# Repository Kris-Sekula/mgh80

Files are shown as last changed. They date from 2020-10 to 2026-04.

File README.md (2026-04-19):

# mgh80 - "The Arduino of the 80s"

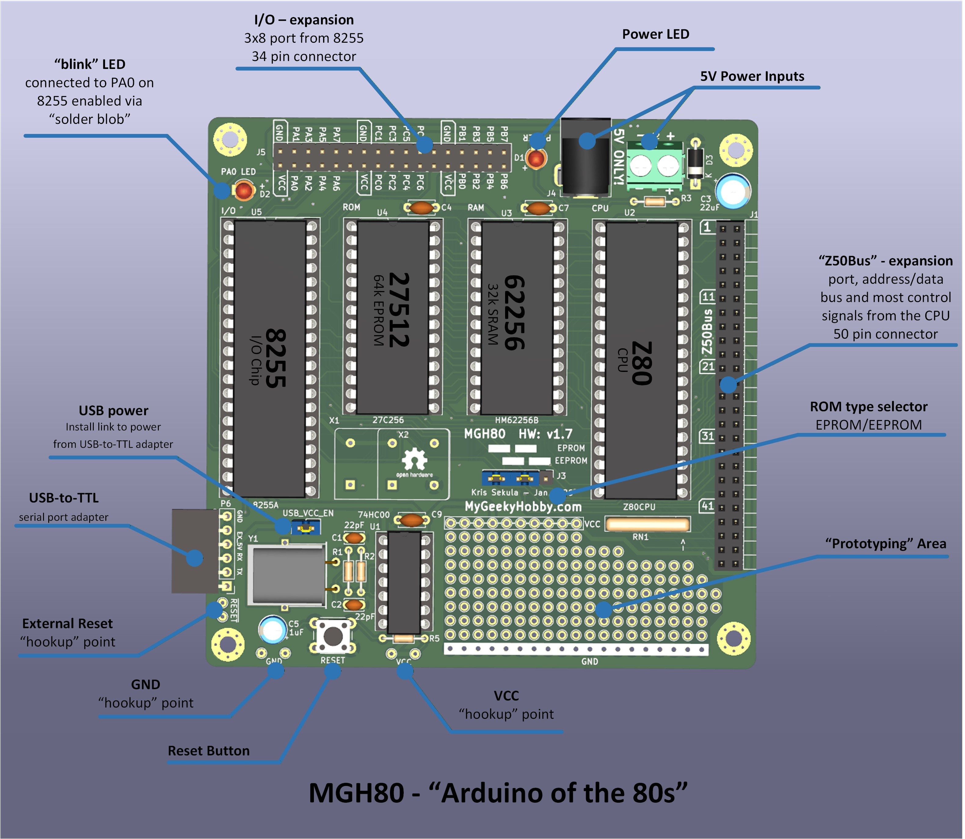
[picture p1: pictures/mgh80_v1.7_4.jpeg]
picture of v1.4c


This 5 chip Z80 single-board "computer", is a very simple Z80 based "controller" with 8255 for I/O plus a ["Z50Bus"](http://linc.no/products/z50bus/) expansion connector. I created it to kick-start my Z80 experiments - breadboarding is fun, but sometimes you want the basics to "just work" so you don't have to troubleshoot loose wires :) 

Features an option to use a local crystal-based oscillator or oscillator module. There is an onboard selector to choose between 27c256 EPROM and 28C256 EEPROM.

You can find more detailed project description on my website [mygeekyhobby.com](https://mygeekyhobby.com/2026/03/07/mgh-80-the-arduino-of-the-80s/)

Onboard address decoder:
* ROM at 0000h - 7FFFh
* RAM at 8000h - FFFFh
* IO at 00h (IOPortA)
* IO at 01h (IOPortB)
* IO at 02h (IOPortC)
* IO at 03h (Control)

A few solder jumpers allow disconnecting various onboard options (if you for example want to provide an external address decoder)... In the basic configuration you should link (with a solder blob) the following:
* JP1 - enable internal CLK source
* JP2 - enable internal IO(8255) address decoder
* JP3 - enable internal ROM address decoder
* JP4 - enable internal RAM address decoder
* JP7 - set 8255 reset pin to GND (bypass R5)
* JP8 - enable onboard LED for port A0 on the 8255
* JP9 - enable onboard IO_WR singal

Simple "blinky" program source (.asm) included and a compiled hex files (.hex) for 27C256 EPROM (or my EPROM emulator). It will toggle all lines of port A a few times a second.

In the "Monitor" folder, you will find sources for a monitor ROM — the bare-metal firmware that boots up, gives you a command prompt, and lets you inspect/modify memory, set breakpoints, and run programs.

Get your PCBs from [PCBWAY](https://www.pcbway.com/project/shareproject/mgh80___the_Arduino_of_the_80s__simple_z80_based__microcontroller____sbc_.html)

A few component kits are listed on [eBay](https://www.ebay.com/sch/avr4sale/m.html?_nkw=&_armrs=1&_ipg=&_from=)

If you found this helpful and you like the work I do, why not buy me a coffee? Thanks! :)



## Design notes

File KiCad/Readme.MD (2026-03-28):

KiCad files to produce the PCB.

Get your PCBs from

PCBWay (https://www.pcbway.com/project/shareproject/mgh80___the_Arduino_of_the_80s__simple_z80_based__microcontroller____sbc_.html)

**Please note:** The address decoder on MGH80 is very simple, as a result not all 8255 will work, (plain 8255A without any dashes in the part name seems to work best) here is a list of known working:

* KS82C55A-8CP
* CP82C55A

Version revisions:

1.7. Added P6 connector for USB-to-TTL bit banged port (see [Monitor](https://github.com/Kris-Sekula/mgh80/tree/main/Monitor#readme) folder)

1.3. Larger holes in the experiments area.

1.2. Fixed issue with EEPROM/EPROM selector.

1.1. Fixed A15 not connected issue.

1.0. First release.

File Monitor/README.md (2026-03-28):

# Simple machine code monitor for MGH80

This is a simple machine code monitor with bit-banged serial port. You can use it on mgh80 by connecting USB-TTL serial adapter as follows:

 External Signal | MGH80 J5
--- | ---
RX | PC3
TX | PC4

** The code is optimised for 4MHz clock frequency **

Example:

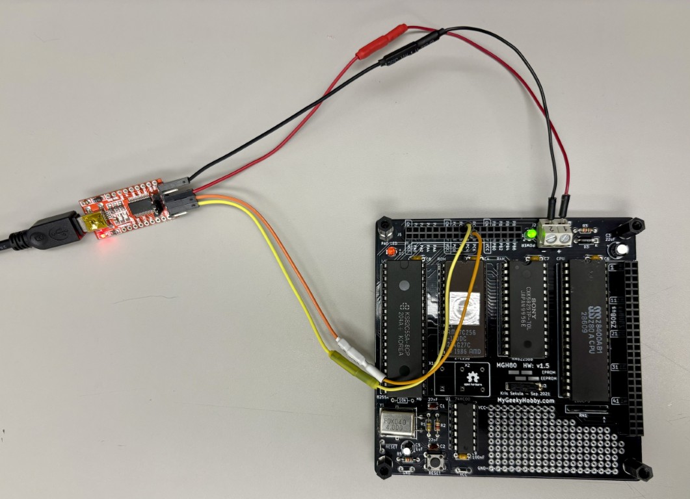
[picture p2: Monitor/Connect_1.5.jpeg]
connect pcb 1.5


If you use PCB v 1.7, I added a port for connectivity:

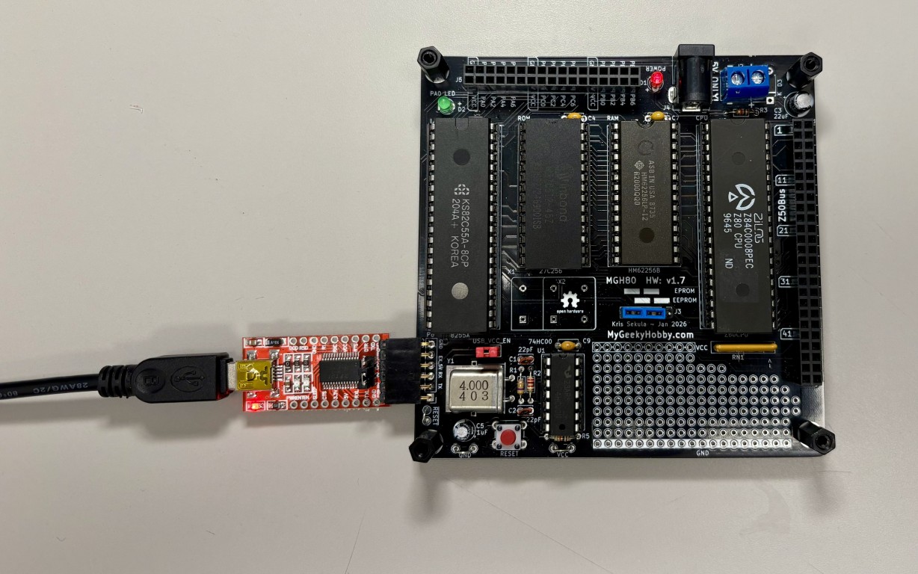
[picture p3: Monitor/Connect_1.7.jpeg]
connect pcb 1.7


I'll shorty share the PCB 1.7 desing files, but for now you can find Gerbers on [PcbWay](https://www.pcbway.com/project/shareproject/mgh80___the_Arduino_of_the_80s__simple_z80_based__microcontroller____sbc_.html)

The monitor offers various commands, hitting "m" displays the full menu:

```
  *** MGH80 - Started ***

>m
 ****** MGH80 Monitor   ***  *** [V8.3mgh 01/2026]  ******
 d  Dump Memory(16 bytes)  D  Dump Memory(256 bytes)
 S  Set Memory             T  ASCI bytes to Memory
 L  LIST                   A  ASSEMBLE
 G  Run from address       g  Run from 8100H
 B  Start BASIC            C  Clear Screen
 O  Write I/O Port         I  Read I/O Port
 f  Flash LEDs 10x         t  Beep Test
 @  Sync                   M/m  Main Menu
 :  Get iHEX Rec.(no echo)
 ;  Send iHEX Rec.(no echo)

>
```

The code includes also BASIC

This is originally based on work of Eric M. Klaus as described here: https://sites.google.com/site/ericmklaus/projects-1/z80minisystem

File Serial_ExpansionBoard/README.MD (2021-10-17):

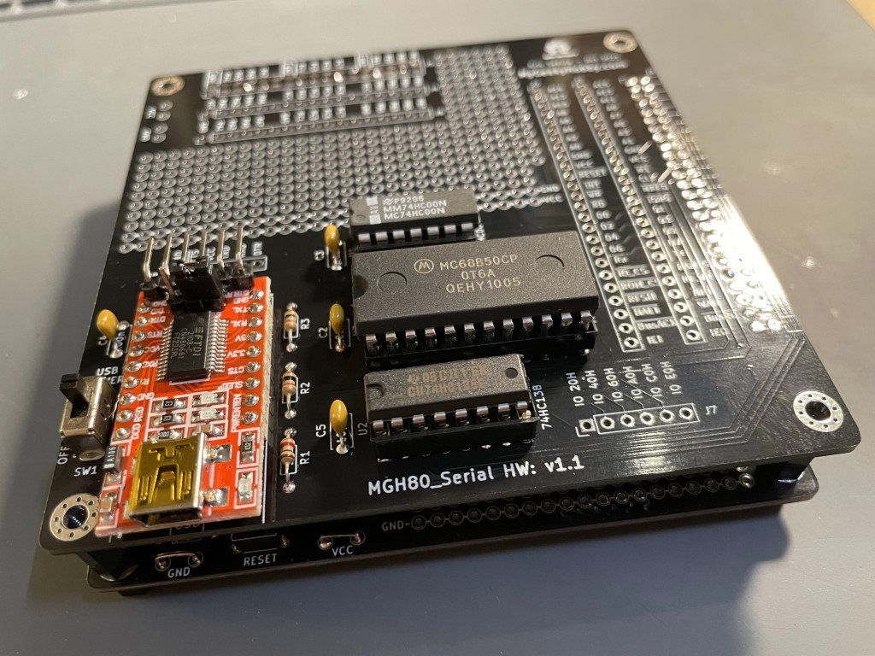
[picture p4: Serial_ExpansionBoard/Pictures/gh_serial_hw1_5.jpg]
picture of serial expansion


This is a serial expansion board using popular Motorola MC68B50. 

MGH80 + Expansion board will run BASIC or "Monitor" style program. 

I use SCMonitor-v100-R3-RC2014-32k-ROM from RC2014 project written by Stephen C Cousins in the United Kingdom.

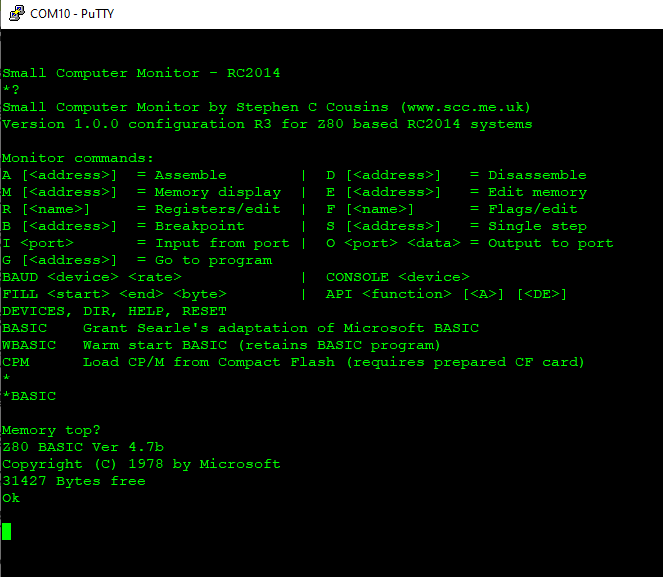
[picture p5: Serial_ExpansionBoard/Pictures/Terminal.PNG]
picture of serial expansion


You can download the monitor from his website.

Note: For this board to work correctly with MGH80 you will need to:
1. Use a 7.3728MHz crystal.
2. Disable onboard IO decoder.
3. Disable onboard IO_WR.

Note: the IO_WR signla was added to MGH80 in PCB ver 1.5, if you are using 1.4 you 
will have to cut the WR link between the Z80 and the 8255, and run IO_WR 
from the 8255 to Z50Bus pin 41. This is only needed for 82C55-2 or
82C55-5 chips, standard CP82C55A works fine.

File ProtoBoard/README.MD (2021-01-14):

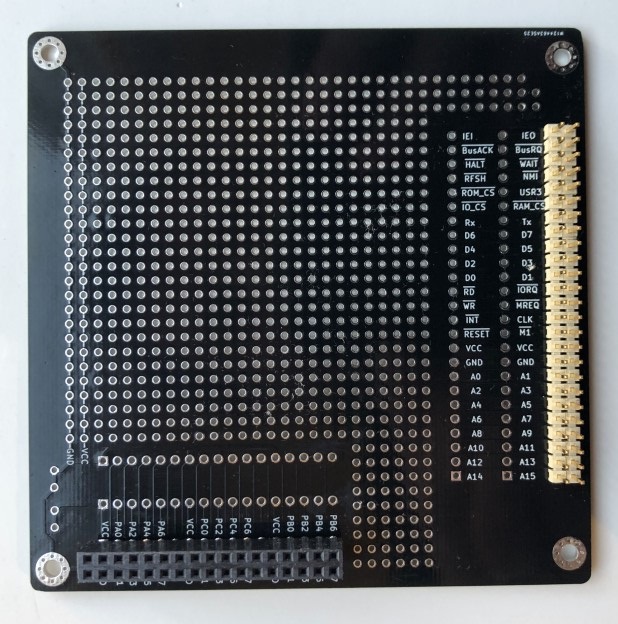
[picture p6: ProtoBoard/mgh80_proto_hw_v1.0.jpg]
picture of v1.0


This is a companion board to mgh80. It extends the I/O connections and the z80Bus to a prototyping board giving you a larger "experiments area".

All signals are marked with a label.

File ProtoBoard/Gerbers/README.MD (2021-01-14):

v1.0 produced by PCBWAY seem to work fine, there is not much to it.

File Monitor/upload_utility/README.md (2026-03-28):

# Simple upload utility

Here you will find a simple "command line" utility to upload Intel .HEX files to the MGH80 Board

This is a command line program (so simply clicking on it won't do much)

## How to use it:

### Windows executable:

From a command window prompt enter:  
```
mgh80load.exe {filename} {port#} {Y}
```

Where:

**{filename.hex}** - is the name of an intel hex file

**{port#}** - is the serial port number (number only, so put **3** instead of **COM3**) 

**{Y}** - this is optional parameter that will make the board automatically start executing code form address 0x8100h

Example:  
```
mgh80load.exe MGH80_blink.hex 3 Y
```

this will upload the file MGH80_blink.hex to the board using COM3 and start the program after upload

### Python script (linux or macOS):

Microsoft keeps making self compiled program execution more and more difficuilt. If you're having issues staring mgh80load.exe on your computer (or you want to run it on Linux machine)
Install python and run the python script, parameters are the same, here is an example:

From command prompt (or linux shell):

```
python mgh80load.py MGH80_blink.hex 3 Y
```

this will upload the file MGH80_blink.hex to the board using COM3 and start the program after upload

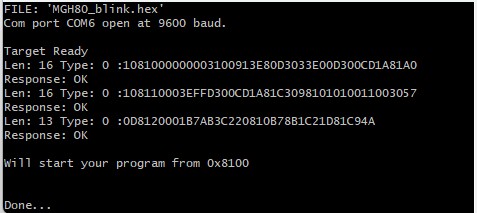
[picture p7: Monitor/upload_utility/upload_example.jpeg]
upload example


### Paste HEX file directly to the monitor:

You can also "paste" the content of the hex file into the the monitor window, but keep in mind the device has no flow controll so it is easy to overload it with text.
I succesfully used "TeraTerm" program on Windows, but added 20ms charater delay and 120ms line delay in serial settings. You only need to send data records, here is an example:

```
:1081000000003100913E80D3033E00D300CD1A81A0
:108110003EFFD300CD1A81C3098101010011003057
:0D8120001B7AB3C220810B78B1C21D81C94A
:00000001FF
```

Since we only need "data records" we can skip the last line:

```
:1081000000003100913E80D3033E00D300CD1A81A0
:108110003EFFD300CD1A81C3098101010011003057
:0D8120001B7AB3C220810B78B1C21D81C94A
```

Pasting this into TeraTerm window will "upload" into mgh80 (note there is no echo, for each line it only shows ":" for start of hex record and "*" to confirm the crc was correct for this line.

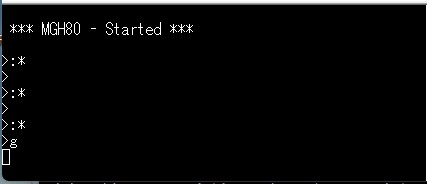
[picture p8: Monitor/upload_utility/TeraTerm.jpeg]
upload example 2


The last "g" command, starts execution.

Source for the windows utility is included.

This is originally based on work described here: https://sites.google.com/site/ericmklaus/projects-1/z80minisystem

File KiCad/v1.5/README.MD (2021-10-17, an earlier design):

In version 1.5 I introduced way to disconnect the 8255 from the Z80 WR signal by the means of jumper JP9. 
This was required as some of the 8255 were found to be problematic when using external IO Decoder (like the one used in the serial expansion board).

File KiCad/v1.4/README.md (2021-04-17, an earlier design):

In version 1.4 I've added an LED to port PA0 of the 8255, this way you can test "blinky" program without connecting external LED (similar to how it is done on a traditional Arduino board)

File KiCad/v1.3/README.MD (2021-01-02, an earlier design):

New in 1.3, increased the size of the holes in the prototyping area to allow for standard pinheaders installation.

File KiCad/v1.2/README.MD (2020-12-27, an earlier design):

Fixed issue with compatybility of the EEPROM/EPROM selector with the onboard simple address decoder. WE of the EEPROM is now plugged to a pull-up resistor via RN1.

As of December 26th 2020 Gerber files generated only but not tested yet, when I run a next batch of the PCBs I'll update here.

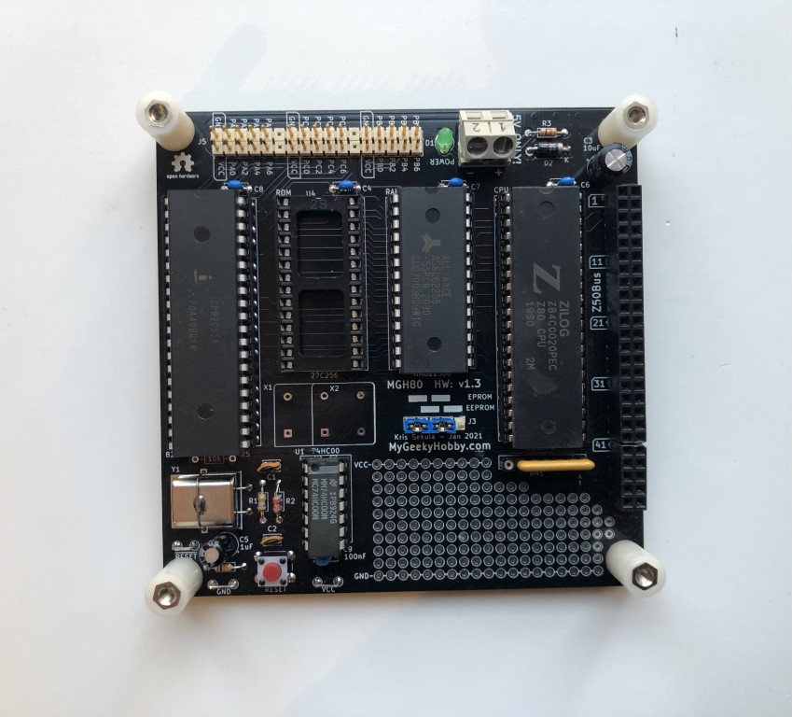
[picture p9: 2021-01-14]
mgh80_v1.3_front.jpg

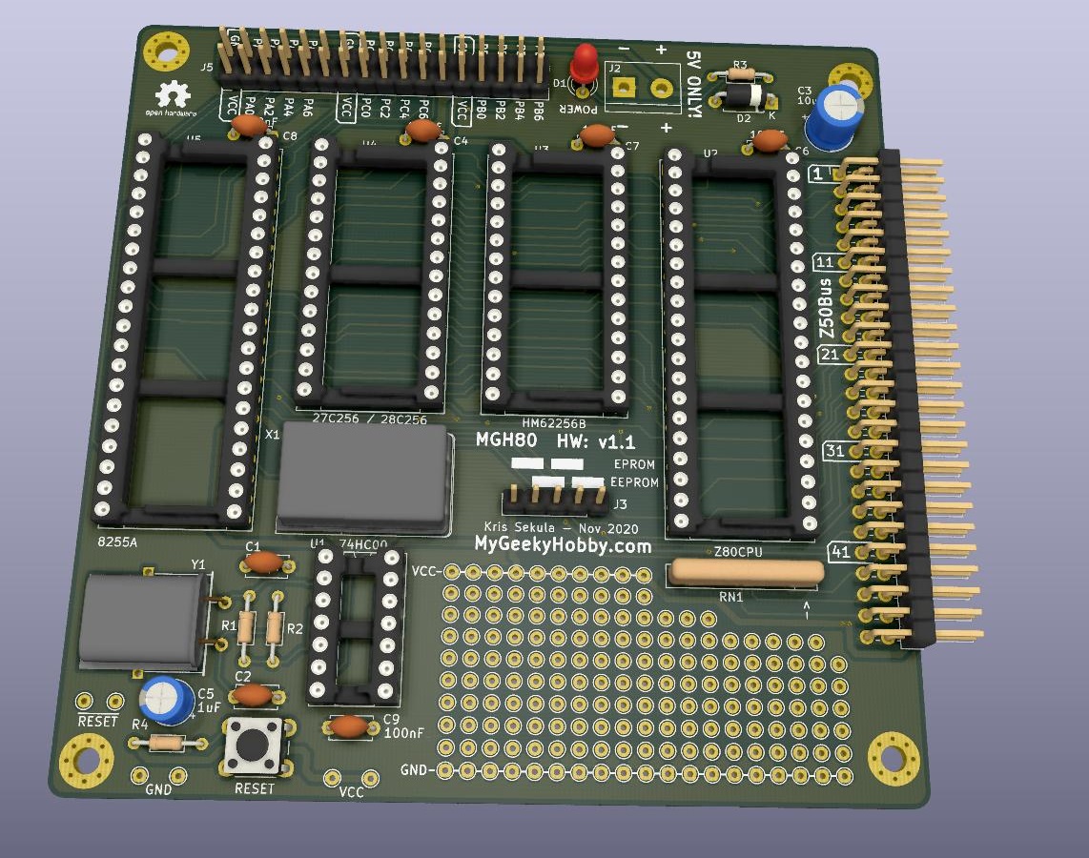
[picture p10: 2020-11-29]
mgh80_1.1.jpg

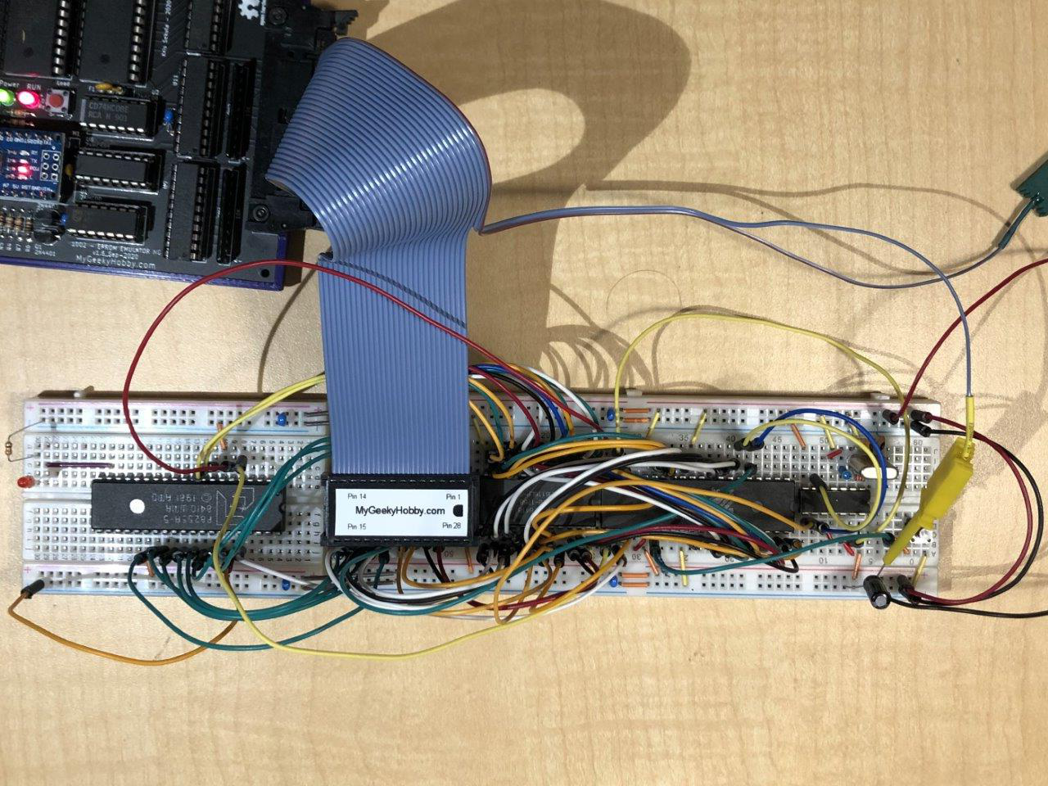
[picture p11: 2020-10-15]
Breadboard.jpg

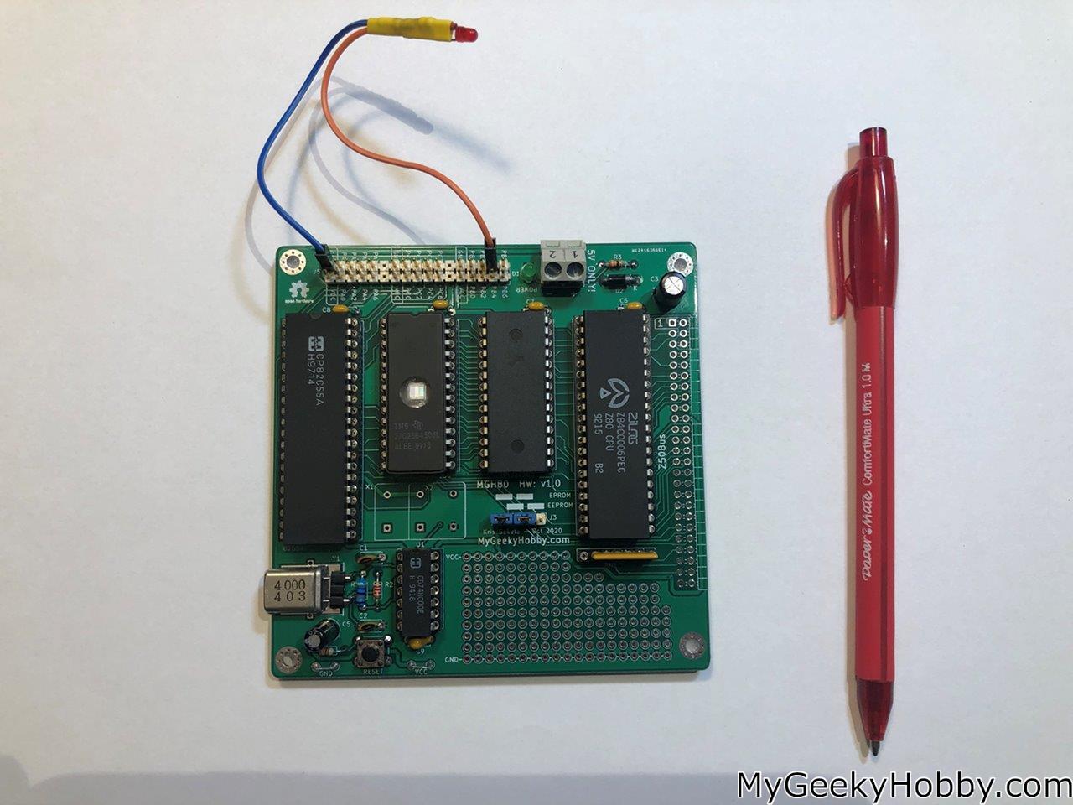
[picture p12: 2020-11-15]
MGH80_v1.0_front.jpg

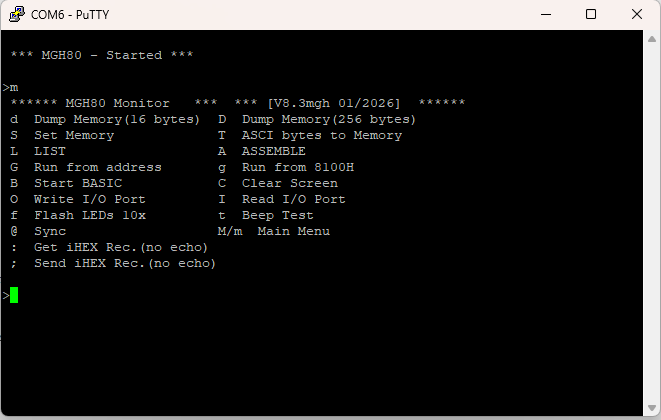
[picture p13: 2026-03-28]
Monitor/Monitor.png

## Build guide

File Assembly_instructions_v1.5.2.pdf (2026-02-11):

“MGH80” Z80 controller DIY kit – Assembly Instructions.

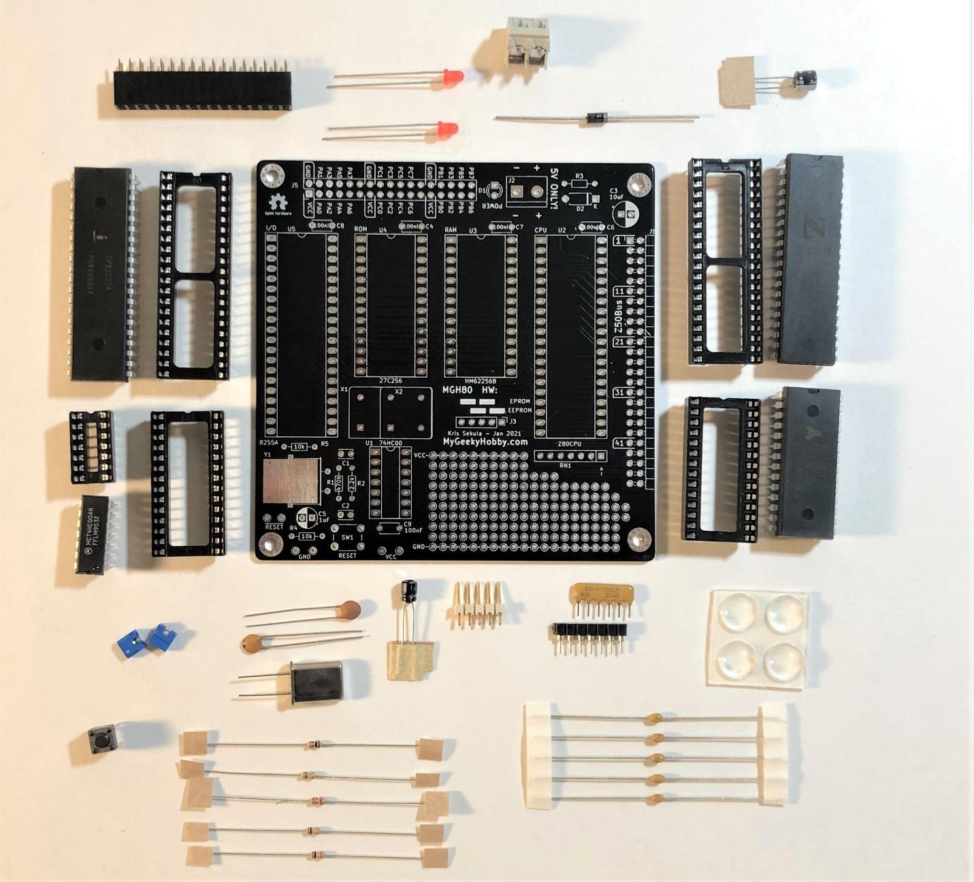
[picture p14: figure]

MyGeekyHobby.com ver 1.5.2 – February 2026

Thank you for purchasing the “MGH80” Z80 Controller DIY Kit, following is a brief assembly instruction.

MGH80 – Assembly Instructions. MyGeekyHobby.com ver 1.5.2 – Feb 2026

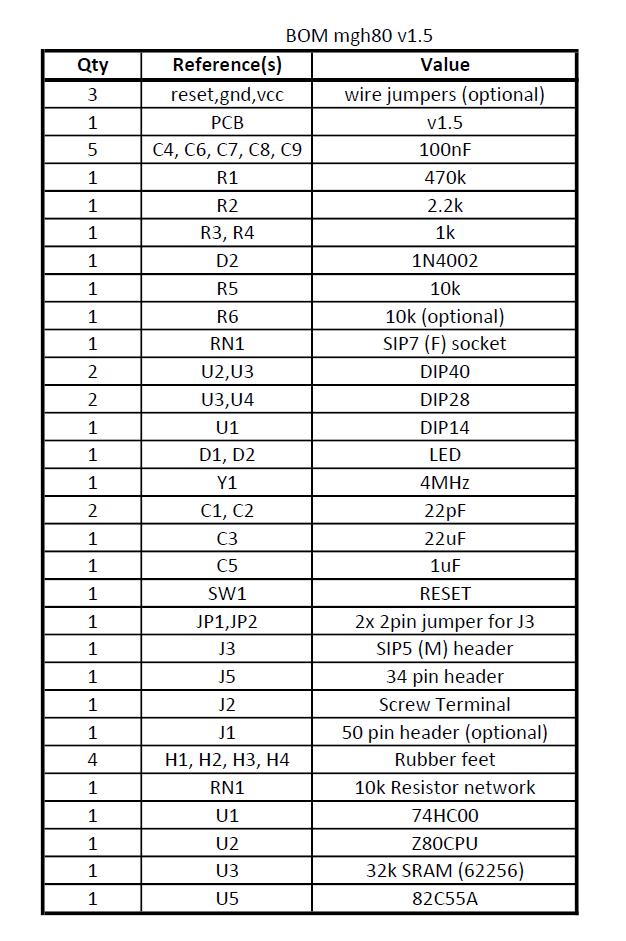
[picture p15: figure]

© MyGeekyHobby.com 2021 - 2026

This document is being updated regularly, check my GitHub page for updates:

https://github.com/Kris-Sekula/mgh80

1. Configure the board option jumpers at the bottom of the PCB.

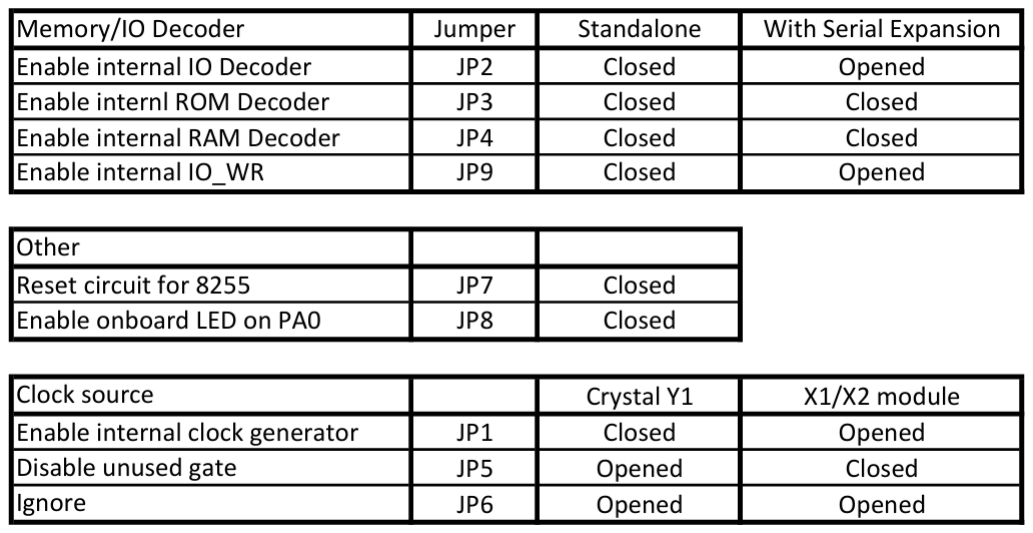
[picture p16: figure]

Basic MGH80 should be configured as follows: using a “blob” of solder close JP1, JP2, JP3, JP4 and JP7, JP8, JP9, but JP5 and JP6 are should be left opened.

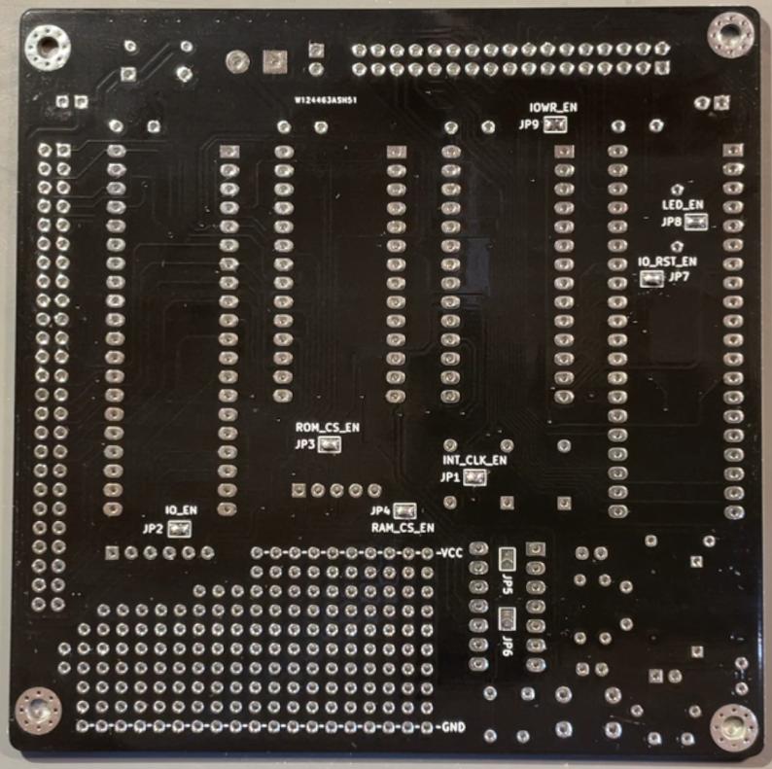
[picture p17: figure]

Note: If you are also using the “Serial Expansion board”, leave JP2 and JP9 opened.
2. Start populating components from the shortest to the tallest: R3,R4(1k), R1(470k), R2(2k2), R5(10k)…diode D3 (1N4001) pay attention to D3 polarity (white band):

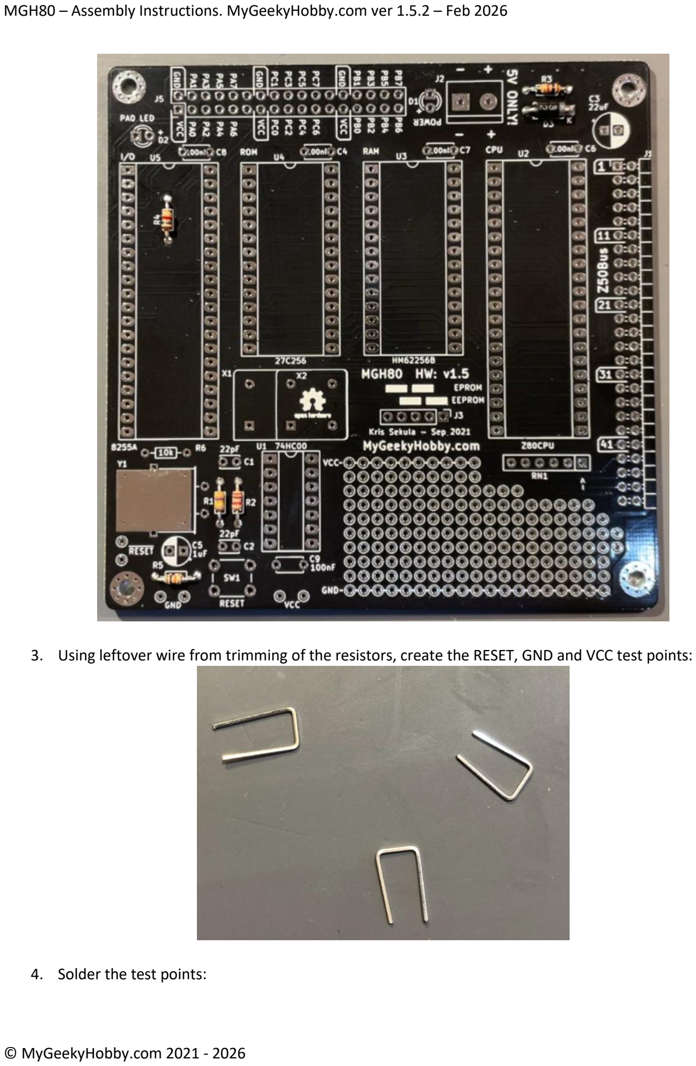
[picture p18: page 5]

3. Using leftover wire from trimming of the resistors, create the RESET, GND and VCC test points:
4. Solder the test points:

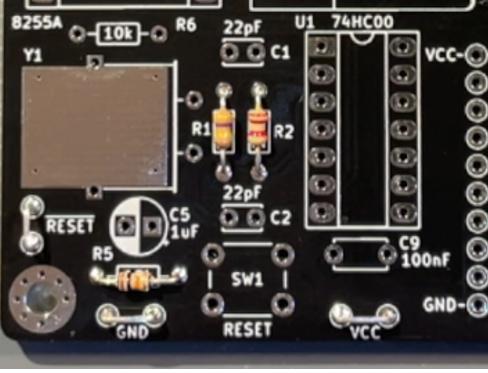
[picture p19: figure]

5. Solder the precision socket for resistor network RN1:

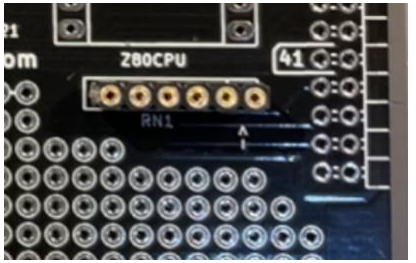
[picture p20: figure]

6. Solder IC Sockets (2x DIP28, 2x DIP40, 1x DIP14):

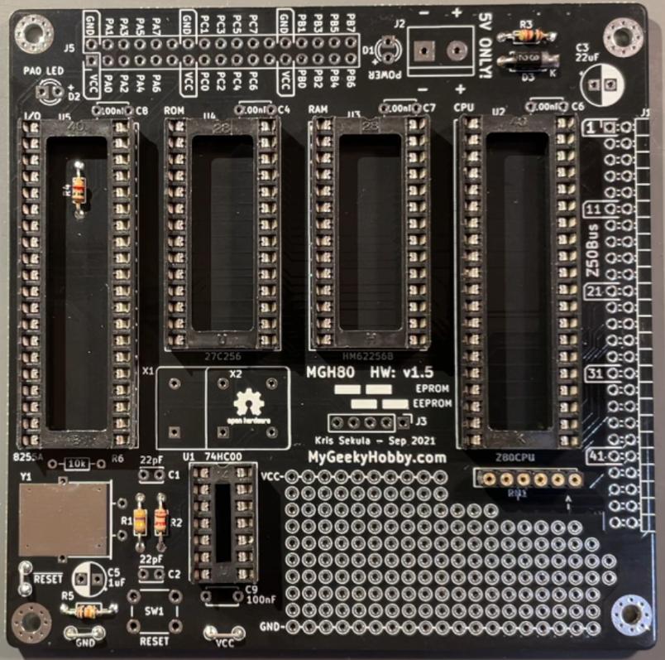
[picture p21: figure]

7. Solder 5 decoupling capacitors C4, C6, C7, C8, C9 (100nF)

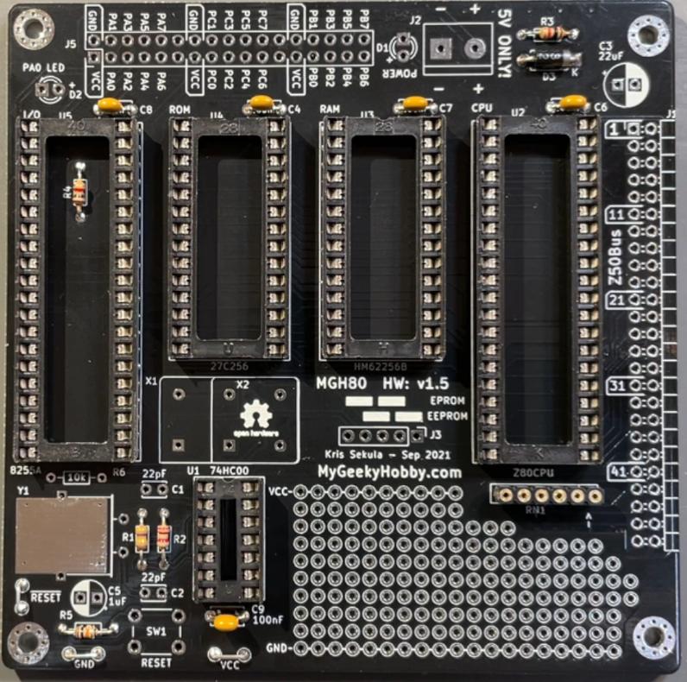
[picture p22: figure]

8. Solder the LED D1 and D2, the positive lead of the LED (Anode) is usually longer and it should be facing the “+” writing on the PCB:

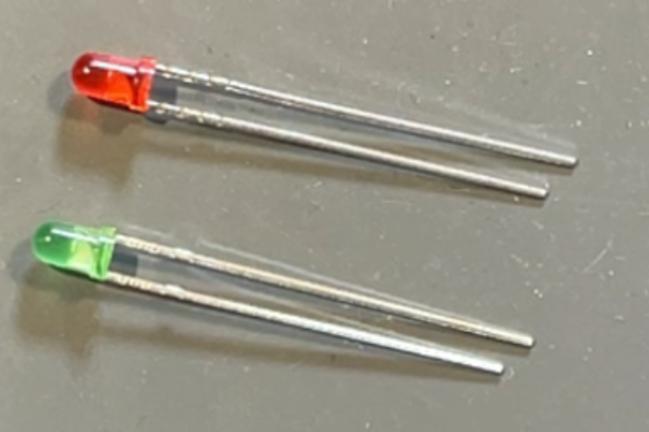
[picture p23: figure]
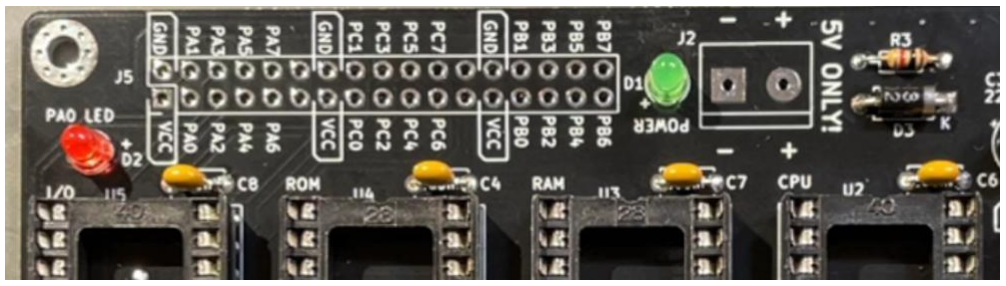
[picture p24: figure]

9. Solder the capacitor C1 and C2 – both are (22pF) and reset switch:

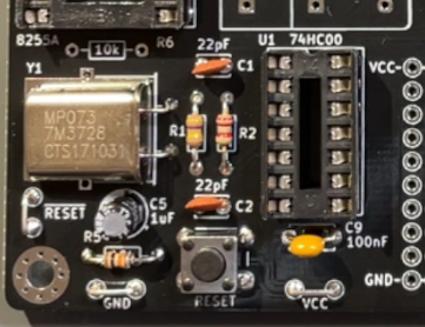
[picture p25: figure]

10. Prepare crystal oscillator Y1 by bending it’s legs 90deg, I use the edge of the PCB to help:

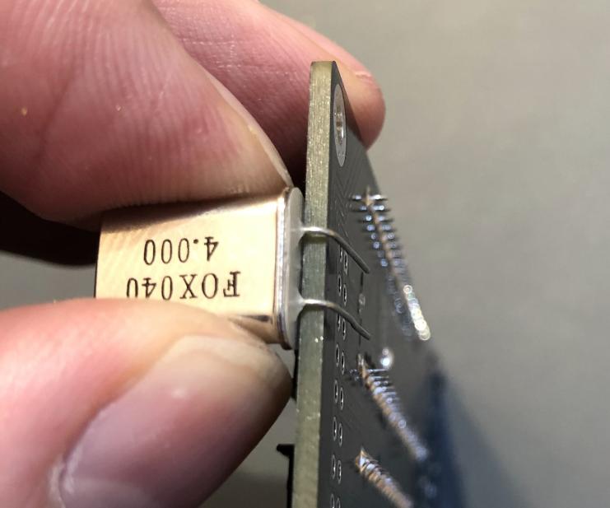
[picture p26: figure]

Note: pictured is a 4MHz crystal, but if you are using the Serial Expansion board, you will need a 7.3728MHz crystal.

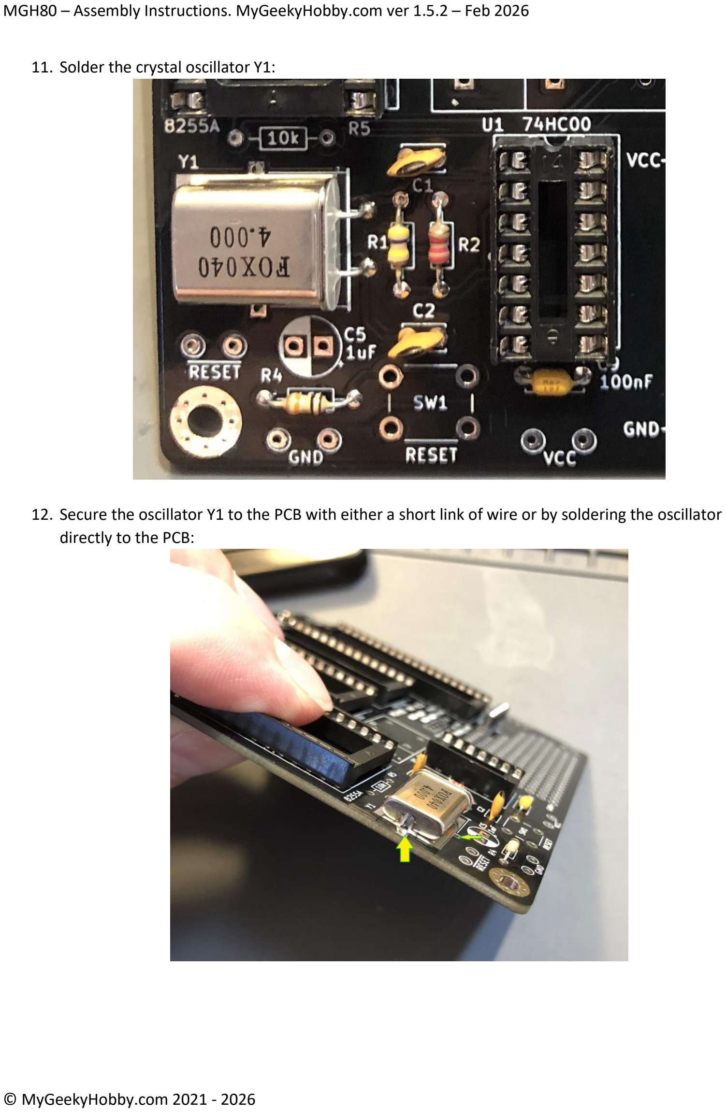
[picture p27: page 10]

11. Solder the crystal oscillator Y1:
12. Secure the oscillator Y1 to the PCB with either a short link of wire or by soldering the oscillator directly to the PCB:

13. Install the electrolytic capacitors C3 (22uF) and C5 (1uF), be careful about polarity, white band on the capacitor marks “-“.

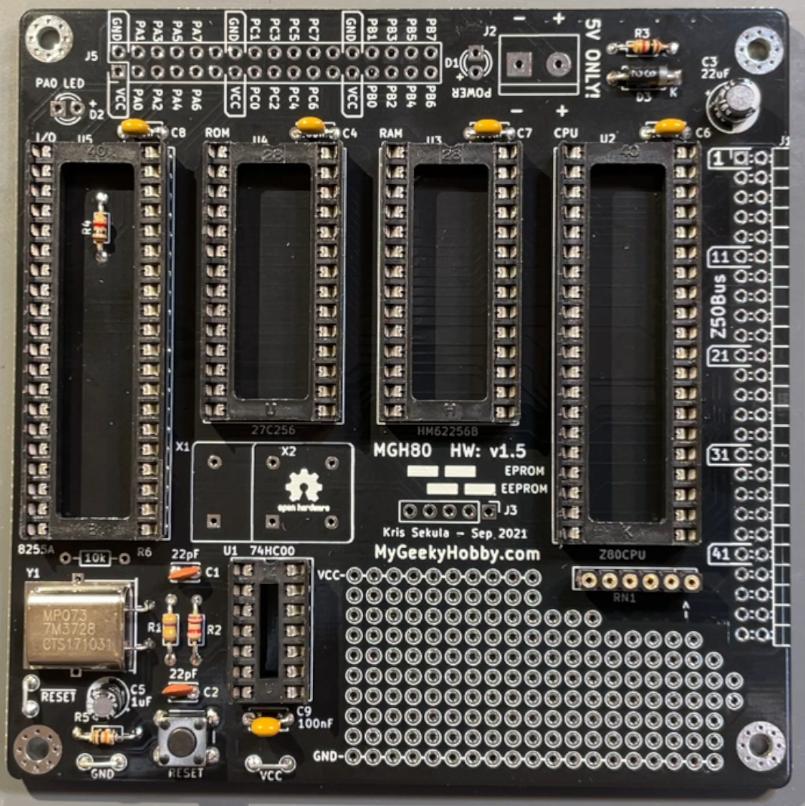
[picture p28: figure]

14. Install the 34pin female connector J5 and 5 pin male header J3

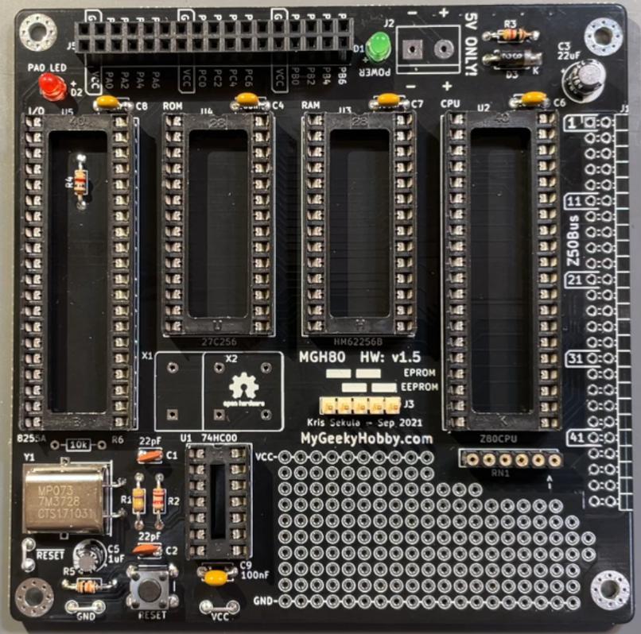
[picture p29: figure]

15. (optional) If you are planning to use the expansion board, install the z50bus connector, for “stacking” use 50 pin female header, for “bus” expander, use a 90deg bent 50pin male header:

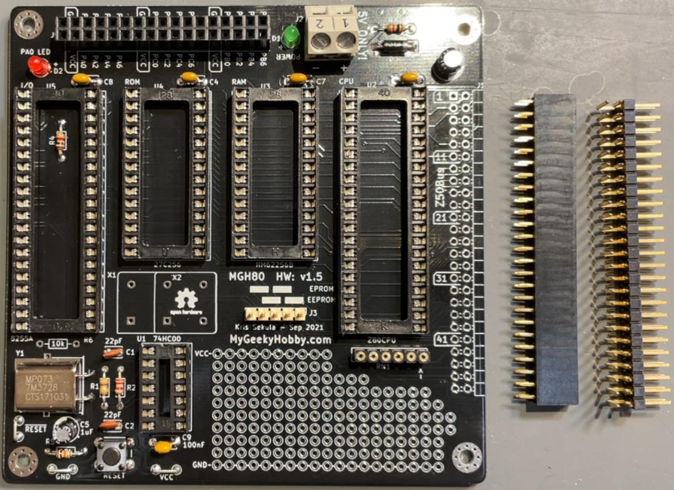
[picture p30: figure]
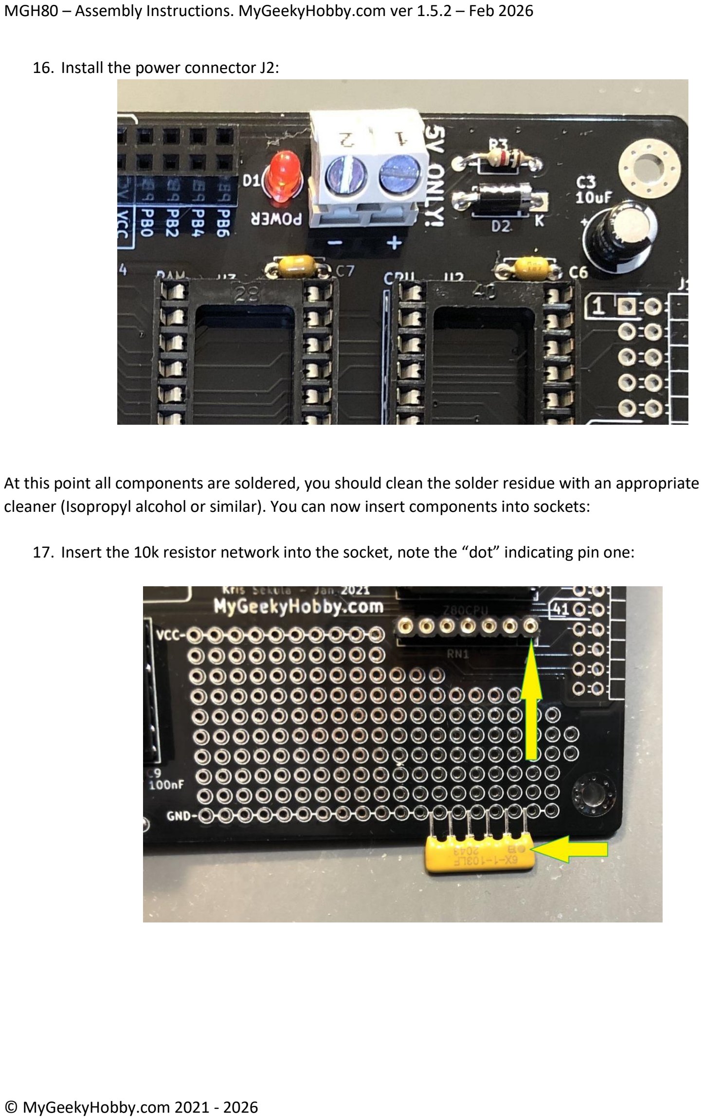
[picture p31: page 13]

16. Install the power connector J2:

At this point all components are soldered, you should clean the solder residue with an appropriate cleaner (Isopropyl alcohol or similar). You can now insert components into sockets:

17. Insert the 10k resistor network into the socket, note the “dot” indicating pin one:

18. Insert the CPU in U2, the RAM in U3 and the IO in U5 and the logic gate into U1

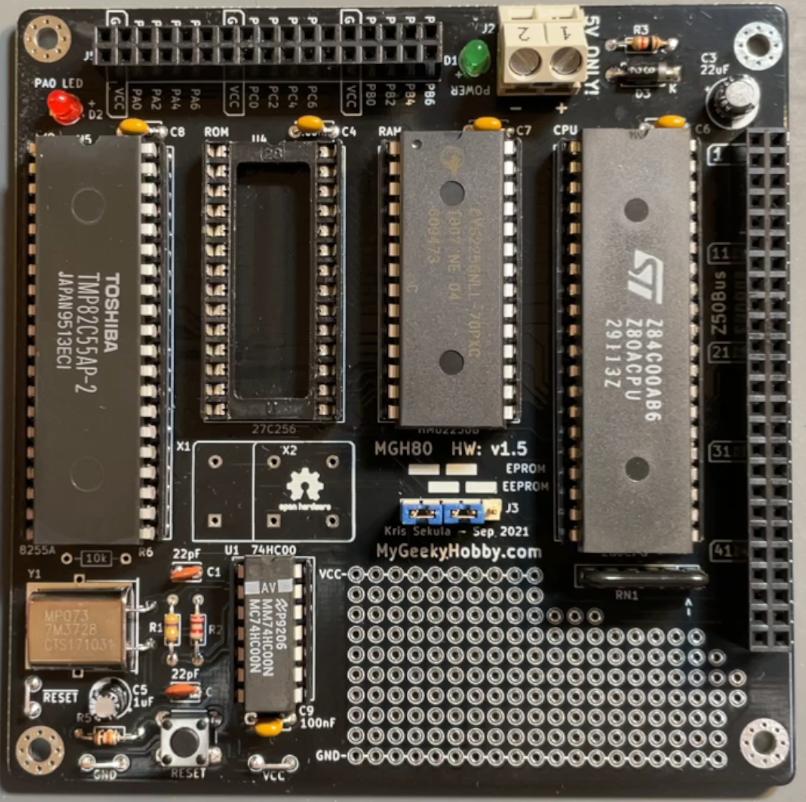
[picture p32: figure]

19. Attach the provided rubber feet to the bottom of the PCB.

20. Depending on the type of ROM used, configure J3 jumpers:
a. 27C256 EPROM memory (blue jumpers on the left of J3) like this:

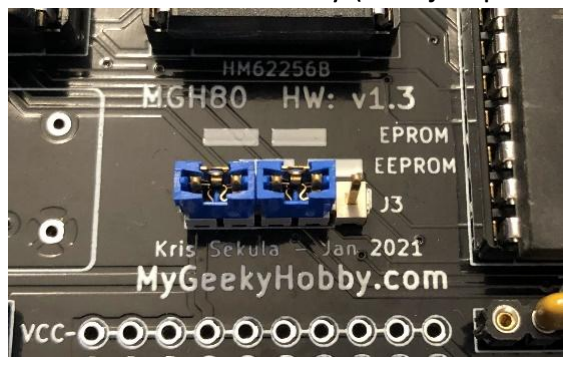
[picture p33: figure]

b. AT28C256 EEPROM (jumpers should be placed to the right of J3).

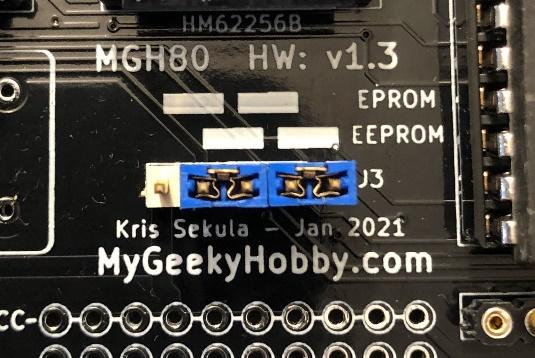
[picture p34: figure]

c. W27C512 EEPROM from Winbond: those as pretty cheap on eBay and are pin compatible with EPROM but can be erased electricaly (I’m using the cheap TL866 programmer). Jumpers should be configured as per example a. (EPROM) and since this memory is 64k, you should load the program into the programmer starting at address 0x8000h (as A15 is held high for the 27C256).

You “MGH80” system is ready to use, you can find a simple “blink” program in the GitHub repository.

Legal Notice:

THE SOFTWARE, DESIGN AND/OR HARDWARE IS PROVIDED “AS IS”, WITHOUT WARRANTY OF ANY KIND, EXPRESS OR IMPLIED, INCLUDING BUT NOT LIMITED TO THE WARRANTIES OF MERCHANTABILITY, FITNESS FOR A PARTICULAR PURPOSE AND NONINFRINGEMENT. IN NO EVENT SHALL THE AUTHORS OR COPYRIGHT HOLDERS BE LIABLE FOR ANY CLAIM, DAMAGES OR OTHER LIABILITY, WHETHER IN AN ACTION OF CONTRACT, TORT OR OTHERWISE, ARISING FROM, OUT OF OR IN CONNECTION WITH THE SOFTWARE OR THE USE OR OTHER DEALINGS IN THE SOFTWARE.

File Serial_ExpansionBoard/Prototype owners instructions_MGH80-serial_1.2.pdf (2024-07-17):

MGH80 pcb v1.4b or lower, compatibility with serial expansion card modifications

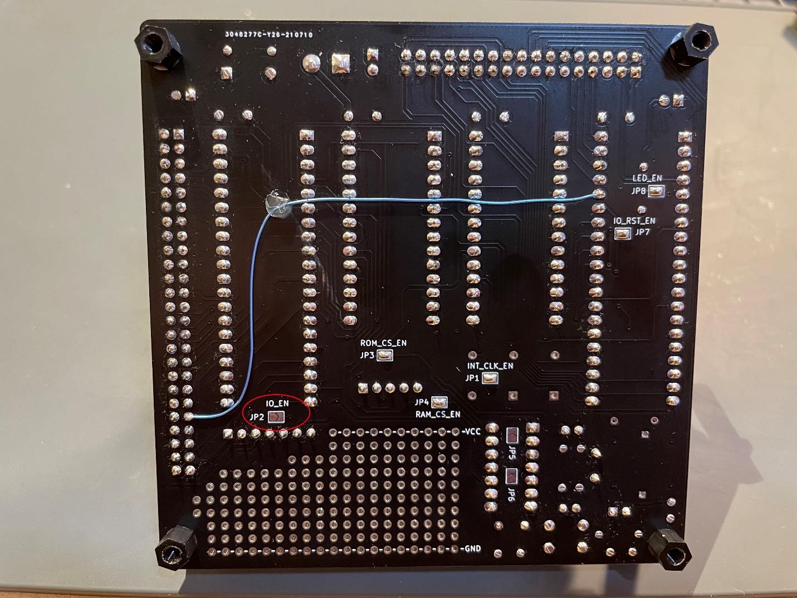
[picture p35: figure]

Document version 1.2

Here are all the information you need to use your MGH80-Serial expansion board (prototype).

I will publish all the information as soon as I have the new PCB version ready and tested, for now attached is just the schematic diagram version 1.1 (your PCB is 1.0 but has been modified to function as 1.1).

To successfully use this expansion board you will need to:

1. Add the provided 50pin female header to your MGH80 (J1).
2. Replace the 4MHz quartz with the provided 7.3728MHz one.
3. Remove the IO_EN solder blob on MGH80 to disable the simple onboard “IO decoder” (see the red circle in the picture below).
4. If your MGH80 is using any PPI chip other than the CP82C55 (for example the TOSHIBA TMP8255AP-2, you will have to modify the MGH PCB to “inject” the new “/IO_WR” signal by cutting the track going to pin 36 of the 8255(WR) and routing pin 41 (USER3) from J1 to pin 36 on the 8255 as pictured.

Re-route pin 41 (USER3) from J1 to pin 36 on 8255

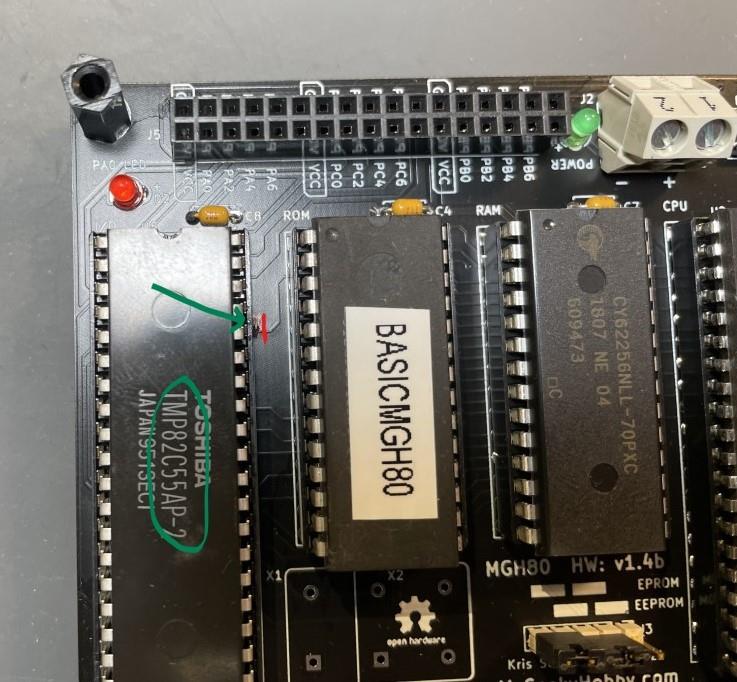
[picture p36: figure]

Cut the /WR signal going to the 8255

5. In terms of firmware you can use the provided EPROM and load “SCMonitor-v100-R3-RC2014-32k-ROM.hex”, for your convenience I already programmed the EPROM, but note you are not paying for the firmware as it is free of charge. This firmware has not been written by me, but is open source and available on the internet. I’ve reached out to the author to get an official permission to distribute the code with my board.
6. A few words on power: the serial expansion board comes with a USB-TTL adapter that can provide power to both the serial adapter and MGH80. There is also a power switch on-board, you should turn it into the ON position, if you want the USB port to be the source of power. Otherwise you can keep it in the OFF position. Note, even in the OFF position the small red LED on the serial adapter will be lit up.

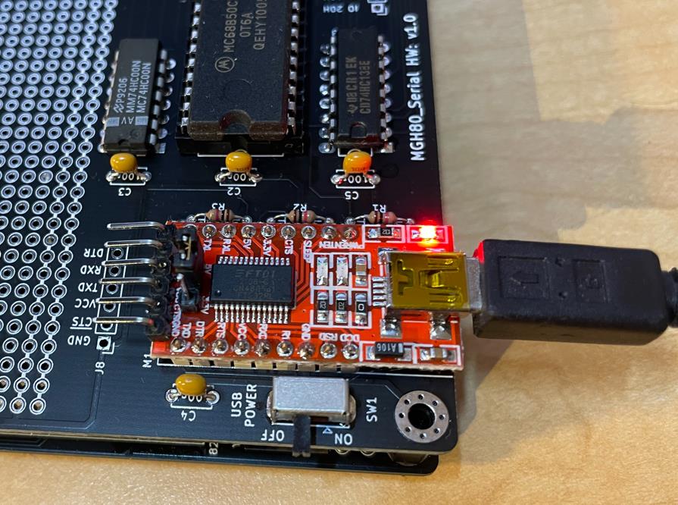
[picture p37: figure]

7. Establishing connection: you will need a serial terminal (screen or putty), set the speed to 115200. The board will initially boot to the SCM “monitor”, you can do some low level commands there (for example to set all lines of port A of the 8255 to logic “1” you would send the following commands:

“o 3 80” command translates to set I/O port 03h to 80h (that is the address of control byte that sets all ports of the 8255 as outputs, “o 0 ff” changes the lines of Port A to “1” and “o 0 0” changes the level back to “0” on all outputs of port A.

8. Here is how you start BASIC, from the “monitor” start by typing “BASIC”, when it asks “Memory top?” just hit enter. The small example basic program shows how to control the ports of the 8255 (note basic is not using hex by default, so parameters are provided in decimal).

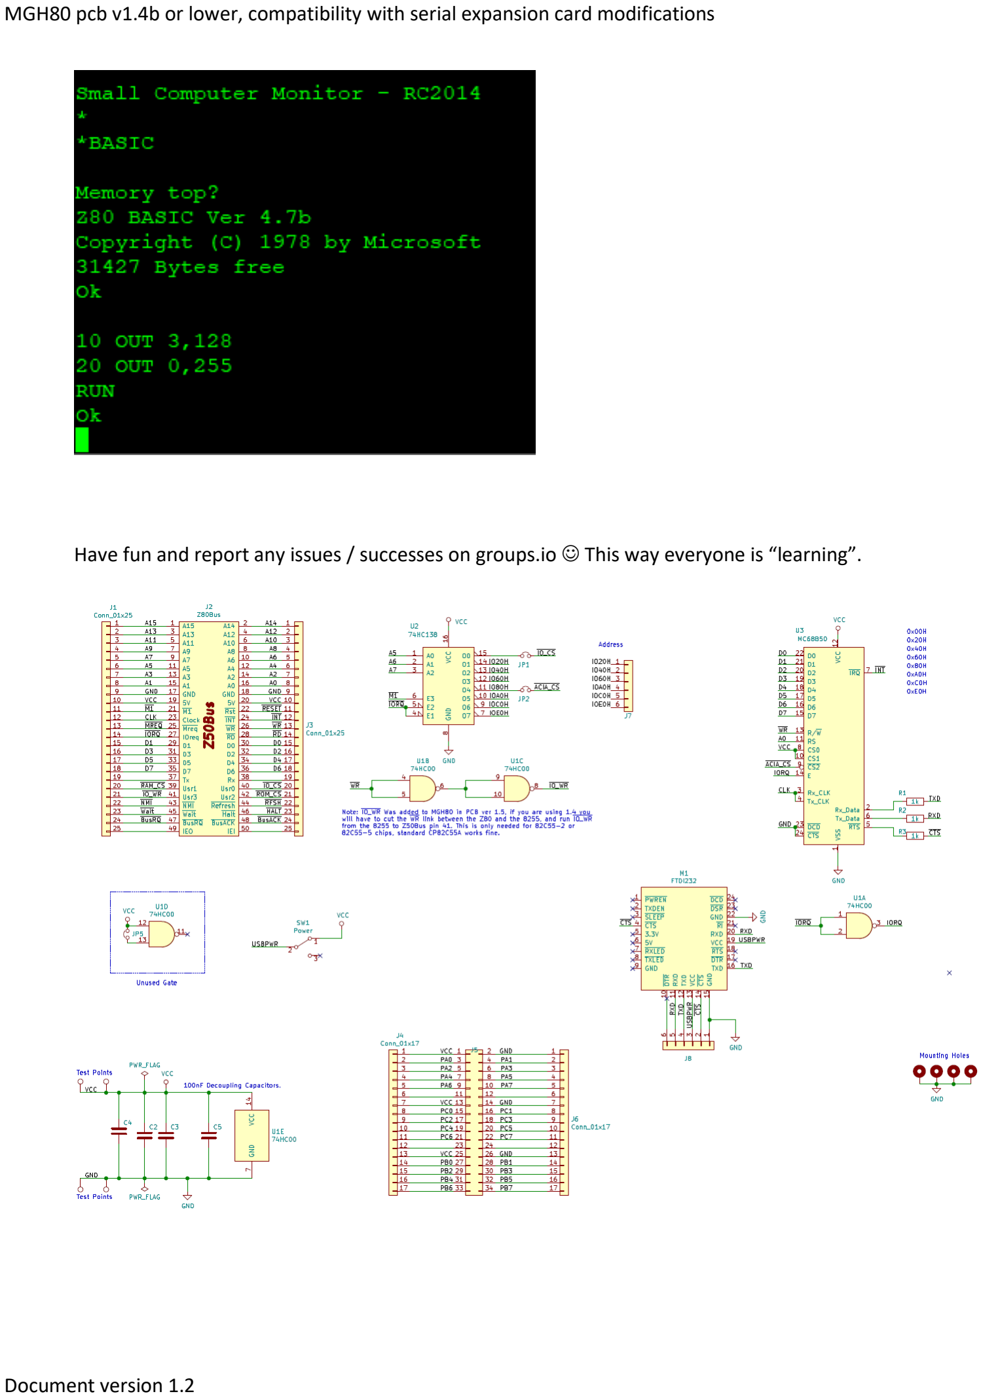
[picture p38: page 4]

Have fun and report any issues / successes on groups.io This way everyone is “learning”.

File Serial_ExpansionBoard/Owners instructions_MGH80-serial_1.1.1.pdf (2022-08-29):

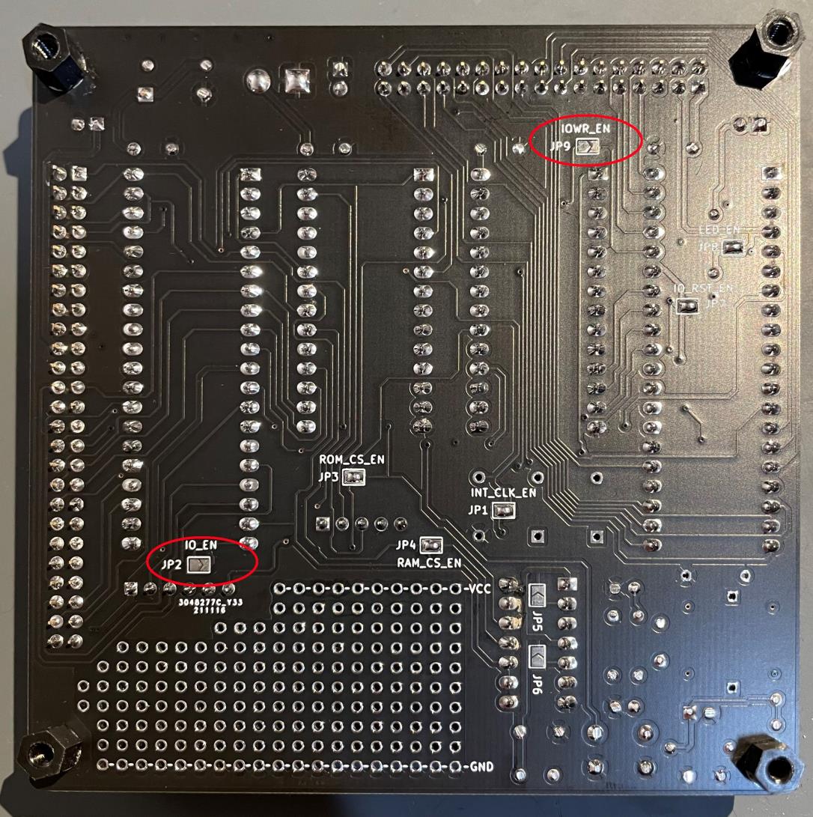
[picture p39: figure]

Doc version 1.1.1

Here are all the information you need to use your MGH80-Serial expansion board.

To successfully use this expansion board you will need to:

1. Double check that you are using 7.3728MHz or 3.6864MHz crystal.
2. Re-configure the solder bridges on MGH80 as follows:
a. Make sure JP9 (IOWR_EN) is left open.
b. Make sure JP2 (IO_EN) is left open.

3. Configure the Serial Expansion board as follows:
a. JP1 (IO_CS) - closed
b. JP2 (ACIA_CS) – closed.
c. JP5 – Closed

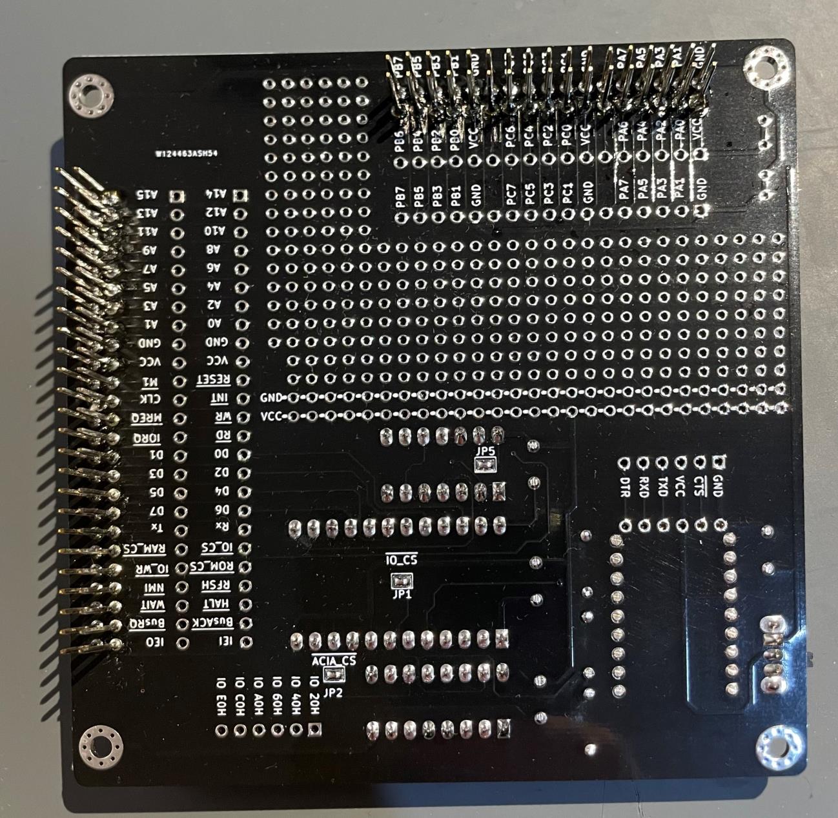
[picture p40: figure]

4. In terms of firmware you can use the provided EPROM and load “SCMonitor-v100-R3-RC2014-32k-ROM.hex”, for your convenience I already programmed the EPROM, but note you are not paying for the firmware as it is free of charge. This firmware has not been written by me, but is open source and available on the internet. I’ve reached out to the author to get an official permission to distribute the code with my board.
5. A few words on power: the serial expansion board comes with a USB-TTL adapter that can provide power to both the serial adapter and MGH80. There is also a power switch on-board, you should turn it into the ON position, if you want the USB port to be the source of power. Otherwise you should keep it in the OFF position. Note, even in the OFF position the small red LED on the serial adapter will still be lit up.


6. Establishing connection: you will need a serial terminal (screen or putty), set the speed to 115200kbps (or 57600bps if 3.6864 MHz crystal is used) . The board will initially boot to the SCM “monitor”, you can do some low level commands there (for example to set all lines of port A of the 8255 to logic “1” you would send the following commands:

“o 3 80” command translates to set I/O port 03h to 80h (that is the address of control byte that sets all ports of the 8255 as outputs, “o 0 ff” changes the lines of Port A to “1” and “o 0 0” changes the level back to “0” on all outputs of port A.

7. Here is how you start BASIC, from the “monitor” start by typing “BASIC”, when it asks “Memory top?” just hit enter. The small example basic program shows how to control the ports of the 8255 (note basic is not using hex by default, so parameters are provided in decimal).

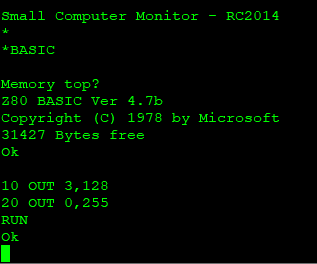
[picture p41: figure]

Have fun and report any issues / successes on groups.io This way everyone is “learning”.

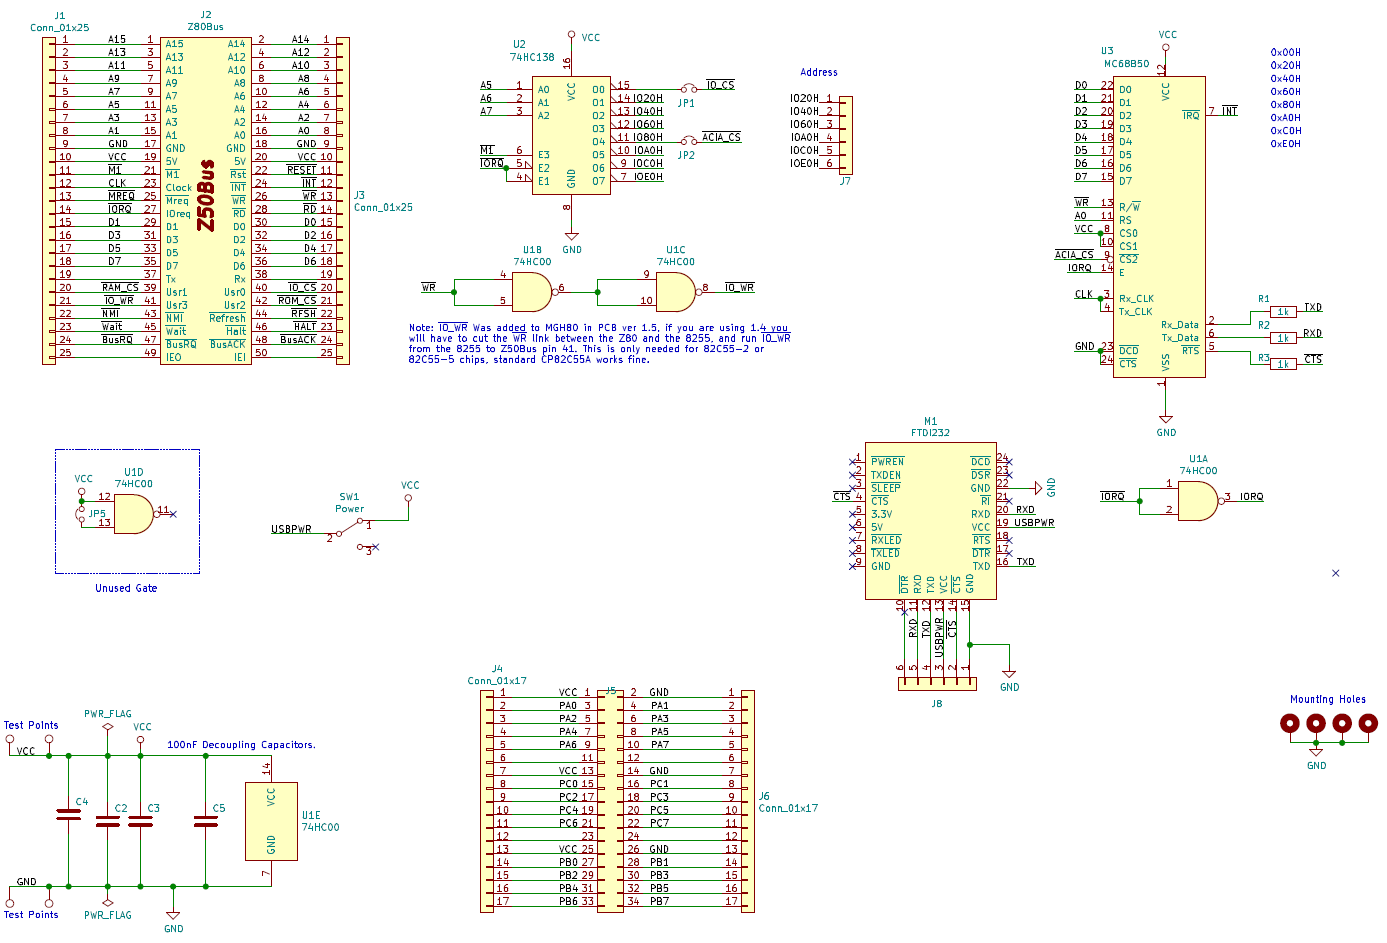
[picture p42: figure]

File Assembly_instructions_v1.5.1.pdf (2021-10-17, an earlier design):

“MGH80” Z80 controller DIY kit – Assembly Instructions.

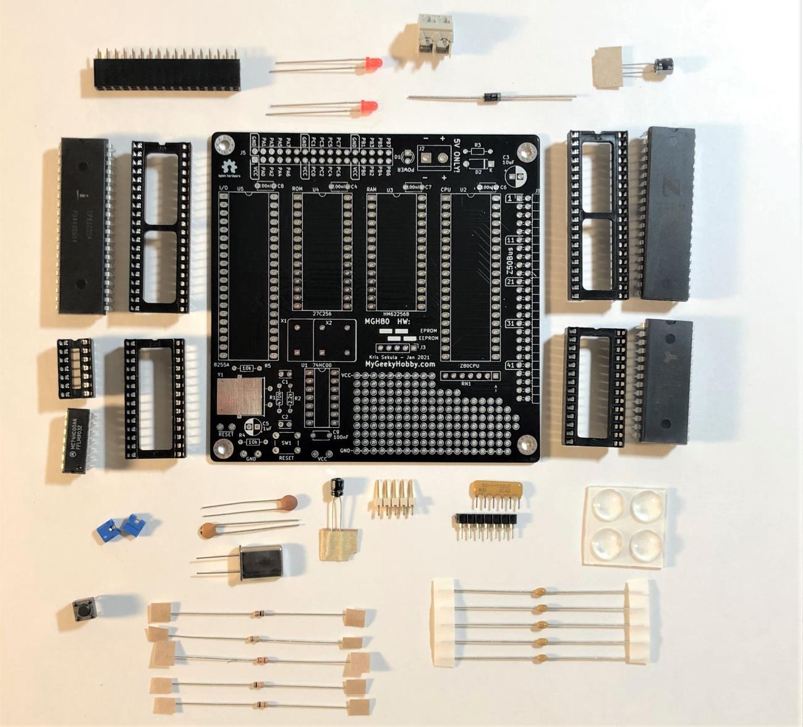
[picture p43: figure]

MyGeekyHobby.com ver 1.5.1 – October 2021

Thank you for purchasing the “MGH80” Z80 Controller DIY Kit, following is a brief assembly instruction.

MGH80 – Assembly Instructions. MyGeekyHobby.com ver 1.5.1 – Oct 2021


© MyGeekyHobby.com 2021

This document is being updated regularly, check my GitHub page for updates:

https://github.com/Kris-Sekula/mgh80

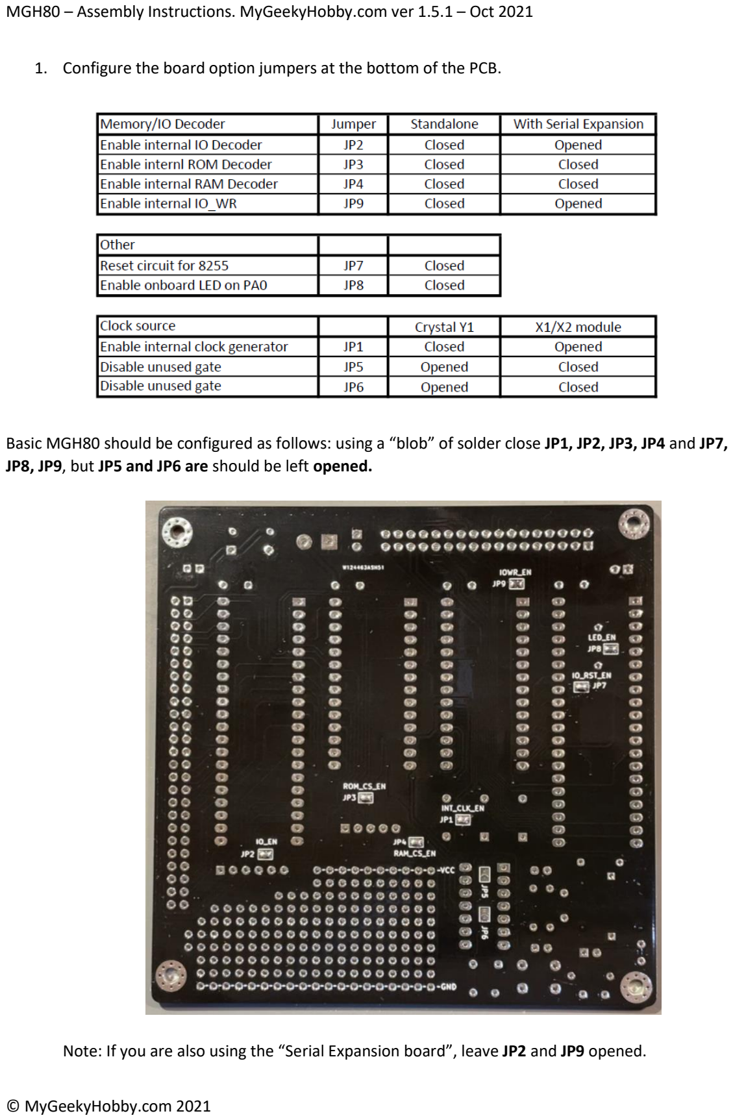
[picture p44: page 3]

1. Configure the board option jumpers at the bottom of the PCB.

Basic MGH80 should be configured as follows: using a “blob” of solder close JP1, JP2, JP3, JP4 and JP7, JP8, JP9, but JP5 and JP6 are should be left opened.

Note: If you are also using the “Serial Expansion board”, leave JP2 and JP9 opened.

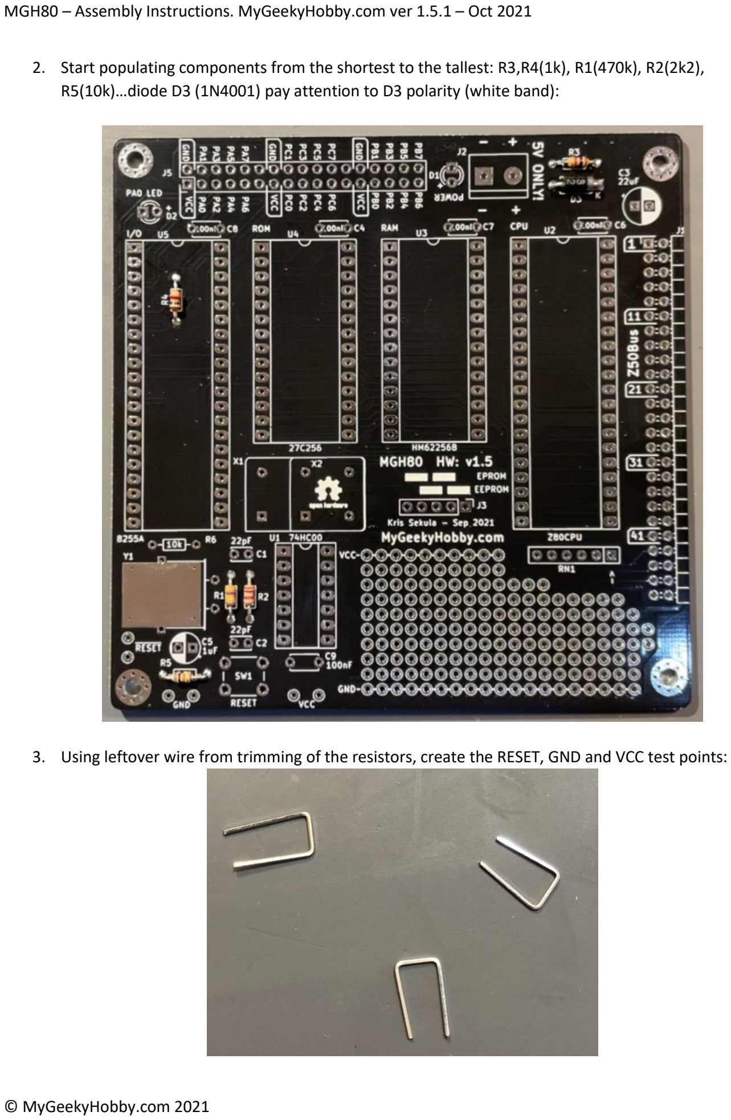
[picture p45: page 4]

2. Start populating components from the shortest to the tallest: R3,R4(1k), R1(470k), R2(2k2), R5(10k)…diode D3 (1N4001) pay attention to D3 polarity (white band):
3. Using leftover wire from trimming of the resistors, create the RESET, GND and VCC test points:

4. Solder the test points:

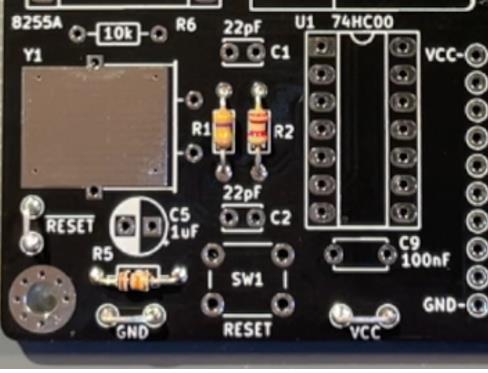
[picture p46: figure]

5. Solder the precision socket for resistor network RN1:

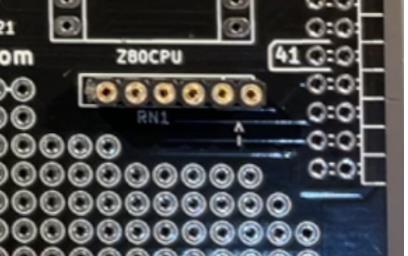
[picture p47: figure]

6. Solder IC Sockets (2x DIP28, 2x DIP40, 1x DIP14):

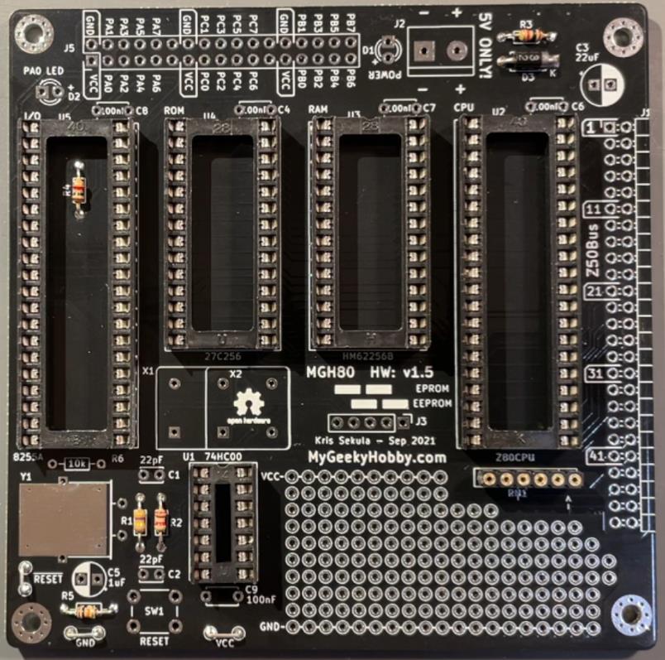
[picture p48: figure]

7. Solder 5 decoupling capacitors C4, C6, C7, C8, C9 (100nF)

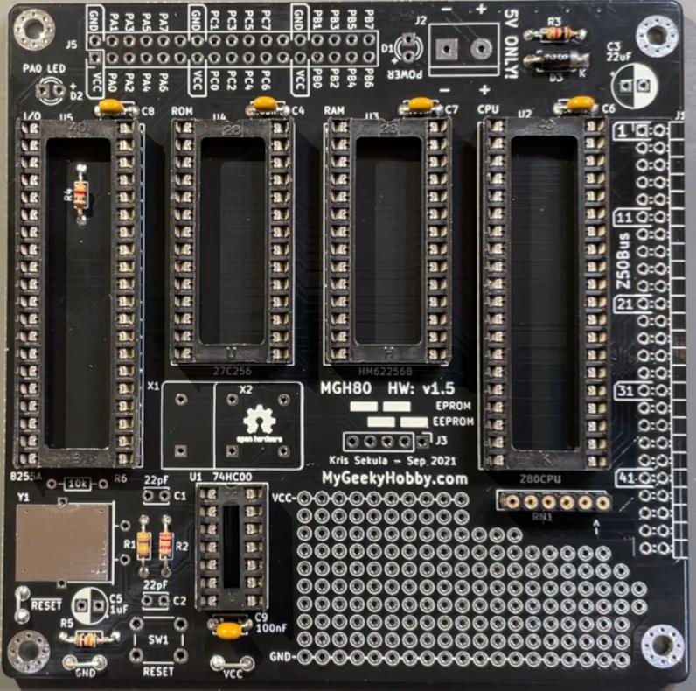
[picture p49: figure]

8. Solder the LED D1 and D2, the positive lead of the LED (Anode) is usually longer and it should be facing the “+” writing on the PCB:

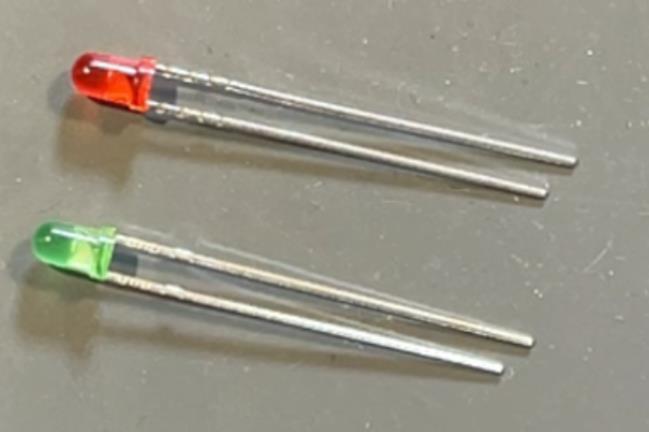
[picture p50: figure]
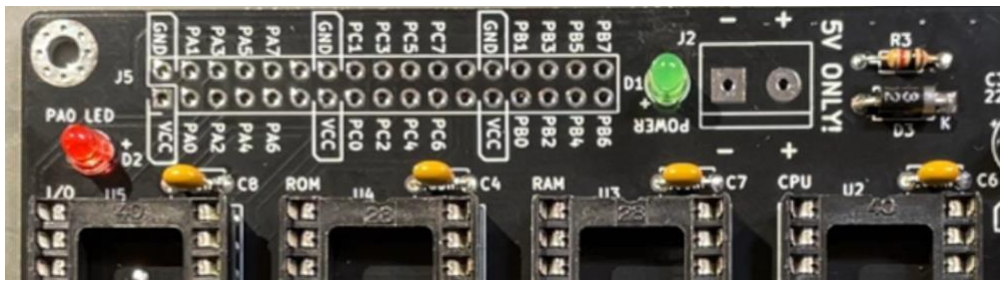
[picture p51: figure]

9. Solder the capacitor C1 and C2 – both are (22pF) and reset switch:

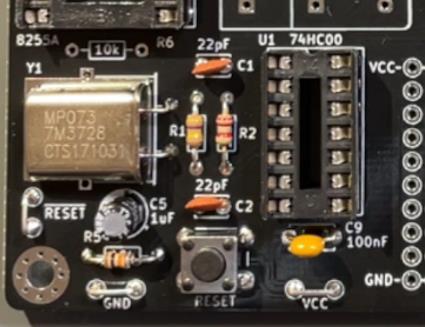
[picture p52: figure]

10. Prepare crystal oscillator Y1 by bending it’s legs 90deg, I use the edge of the PCB to help:

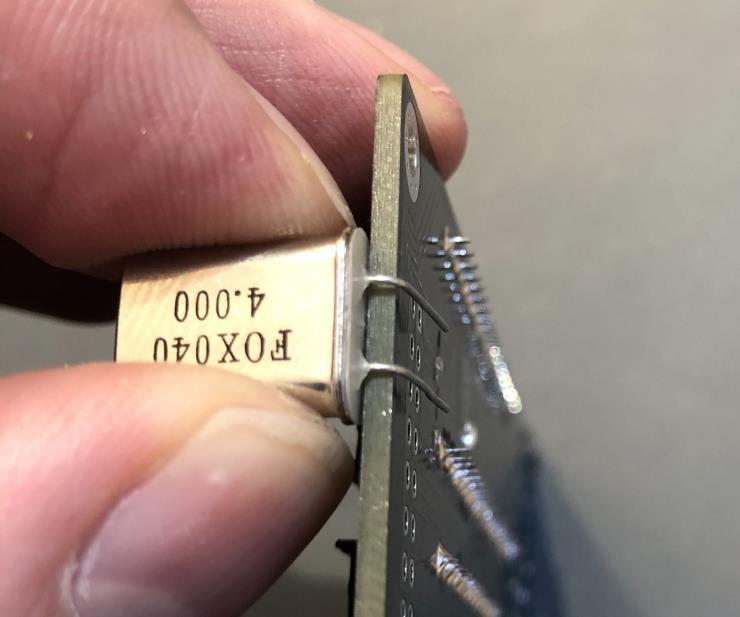
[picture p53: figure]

Note: pictured is a 4MHz crystal, but if you are using the Serial Expansion board, you will need a 7.3728MHz crystal.


11. Solder the crystal oscillator Y1:
12. Secure the oscillator Y1 to the PCB with either a short link of wire or by soldering the oscillator directly to the PCB:

13. Install the electrolytic capacitors C3 (22uF) and C5 (1uF), be careful about polarity, white band on the capacitor marks “-“.


14. Install the 34pin female connector J5 and 5 pin male header J3


15. (optional) If you are planning to use the expansion board, install the z50bus connector, for “stacking” use 50 pin female header, for “bus” expander, use a 90deg bent 50pin male header:


16. Install the power connector J2:

At this point all components are soldered, you should clean the solder residue with an appropriate cleaner (Isopropyl alcohol or similar). You can now insert components into sockets:

17. Insert the 10k resistor network into the socket, note the “dot” indicating pin one:

18. Insert the CPU in U2, the RAM in U3 and the IO in U5 and the logic gate into U1


19. Attach the provided rubber feet to the bottom of the PCB.

20. Depending on the type of ROM used, configure J3 jumpers:
a. 27C256 EPROM memory (blue jumpers on the left of J3) like this:


b. AT28C256 EEPROM (jumpers should be placed to the right of J3).


c. W27C512 EEPROM from Winbond: those as pretty cheap on eBay and are pin compatible with EPROM but can be erased electricaly (I’m using the cheap TL866 programmer). Jumpers should be configured as per example a. (EPROM) and since this memory is 64k, you should load the program into the programmer starting at address 0x8000h (as A15 is held high for the 27C256).

You “MGH80” system is ready to use, you can find a simple “blink” program in the GitHub repository.

Legal Notice:

THE SOFTWARE, DESIGN AND/OR HARDWARE IS PROVIDED “AS IS”, WITHOUT WARRANTY OF ANY KIND, EXPRESS OR IMPLIED, INCLUDING BUT NOT LIMITED TO THE WARRANTIES OF MERCHANTABILITY, FITNESS FOR A PARTICULAR PURPOSE AND NONINFRINGEMENT. IN NO EVENT SHALL THE AUTHORS OR COPYRIGHT HOLDERS BE LIABLE FOR ANY CLAIM, DAMAGES OR OTHER LIABILITY, WHETHER IN AN ACTION OF CONTRACT, TORT OR OTHERWISE, ARISING FROM, OUT OF OR IN CONNECTION WITH THE SOFTWARE OR THE USE OR OTHER DEALINGS IN THE SOFTWARE.

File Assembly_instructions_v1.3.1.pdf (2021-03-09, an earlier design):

“MGH80” Z80 controller DIY kit – Assembly Instructions.


MyGeekyHobby.com ver 1.3.1 – March 2021

MGH80 – Assembly Instructions. MyGeekyHobby.com ver 1.3.1 – March 2021


© MyGeekyHobby.com 2021

Thank you for purchasing the “MGH80” Z80 Controller DIY Kit, following is a brief assembly instruction.

This document is being updated regularly, check my GitHub page for updates:

https://github.com/Kris-Sekula/mgh80

1. Configure the board option jumpers at the bottom of the PCB. Using a solder “blob” connect JP1, JP2, JP3, JP4 and JP7 as highlighted in yellow. JP5 and JP6 are should be left opened.


2. Start populating components from the shortest to the tallest: R3(1k), R1(470k), R2(2k2), R4(10k)… additionally if the supplied 100nF capacitors are the axial type, insert those into the PCB (C8, C4, C7, C6, C9) solder and trim:
3. Using leftover wire from trimming of the resistors, create the RESET, GND and VCC test points:

4. Solder the test points:


(note: other components are shown already soldered, but I changed the order of operations)


5. Solder the precision socket for resistor network RN1:


6. Solder IC Sockets (2x DIP28, 2x DIP40, 1x DIP14):
7. Solder the LED, the positive lead of the LED (Anode) should be facing the “POWER” writing on the PCB:


8. Solder the capacitor C1 and C2 – both are (22pF):
9. Prepare crystal oscillator Y1 by bending it’s legs 90deg, I use the edge of the PCB to help:


10. Solder the crystal oscillator Y1:
11. Secure the oscillator Y1 to the PCB with either a short link of wire or by soldering the oscillator directly to the PCB:


12. Install the electrolytic capacitors:

C5 is 1uF but C3 can be either 10uF or 22uF

13. Install the 34pin female connector J5 and 5 pin male header J3


14. Install the power connector J2:

At this point all components are soldered, you should clean the solder residue with an appropriate cleaner (Isopropyl alcohol or similar). You can now insert components into sockets:

15. Insert the 10k resistor network into the socket, note the “dot” indicating pin one:

16. Insert the CPU in U2, the RAM in U3 and the IO in U5 and the logic gate into U1


17. Attach the provided rubber feet to the bottom of the PCB.

18. Depending on the type of ROM used, configure J3 jumpers:
a. 27C256 EPROM memory (blue jumpers on the left of J3) like this:


b. AT28C256 EEPROM (jumpers should be placed to the right of J3).


c. W27C512 EEPROM from Winbond: those as pretty cheap on eBay and are pin compatible with EPROM but can be erased electricaly (I’m using the cheap TL866 programmer). Jumpers should be configured as per example a. (EPROM) and since this memory is 64k, you should load the program into the programmer starting at address 0x8000h (as A15 is held high for the 27C256).

You “MGH80” system is ready to use, you can find a simple “blink” program in the GitHub repository.

Legal Notice:

THE SOFTWARE, DESIGN AND/OR HARDWARE IS PROVIDED “AS IS”, WITHOUT WARRANTY OF ANY KIND, EXPRESS OR IMPLIED, INCLUDING BUT NOT LIMITED TO THE WARRANTIES OF MERCHANTABILITY, FITNESS FOR A PARTICULAR PURPOSE AND NONINFRINGEMENT. IN NO EVENT SHALL THE AUTHORS OR COPYRIGHT HOLDERS BE LIABLE FOR ANY CLAIM, DAMAGES OR OTHER LIABILITY, WHETHER IN AN ACTION OF CONTRACT, TORT OR OTHERWISE, ARISING FROM, OUT OF OR IN CONNECTION WITH THE SOFTWARE OR THE USE OR OTHER DEALINGS IN THE SOFTWARE.

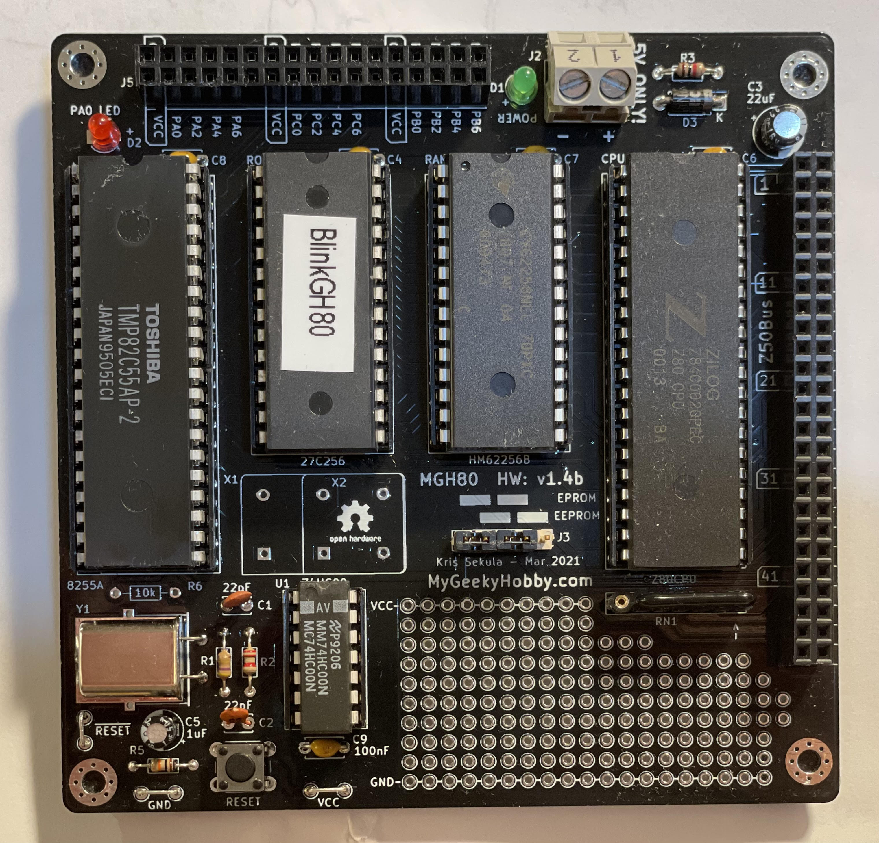
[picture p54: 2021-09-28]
pictures/1.4b_assembled.jpg

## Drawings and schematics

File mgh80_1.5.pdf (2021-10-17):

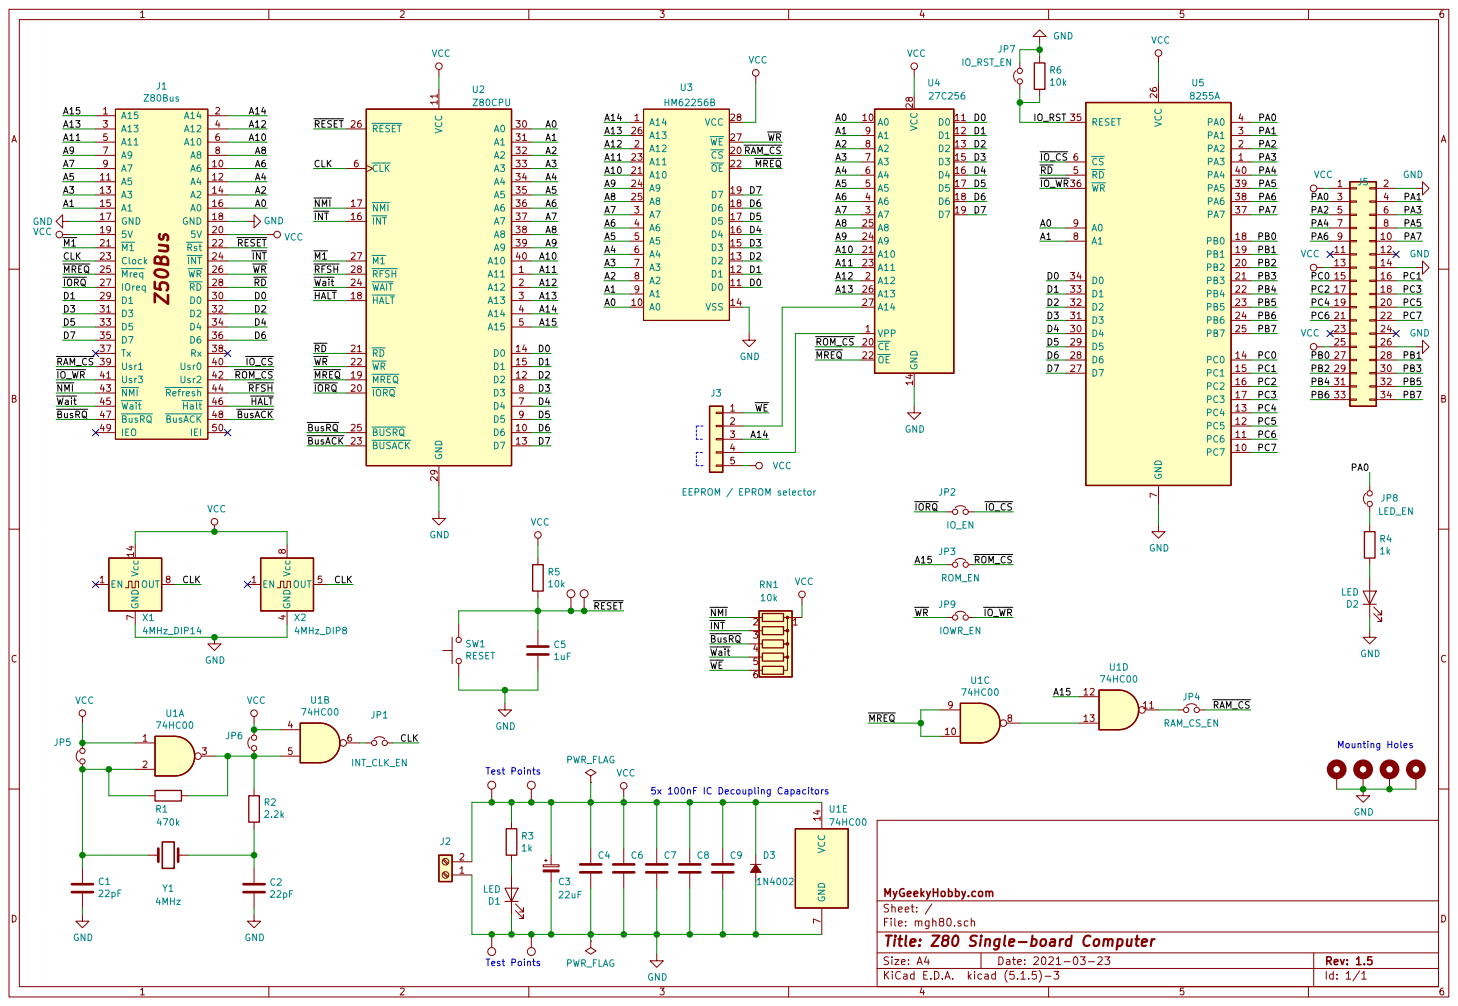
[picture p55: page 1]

J3 EEPROM / EPROM selector VCC

Mounting Holes Test Points

File: mgh80.sch Sheet: / MyGeekyHobby.com Y1

Id: 1/1 Title: Z80 Single-board Computer

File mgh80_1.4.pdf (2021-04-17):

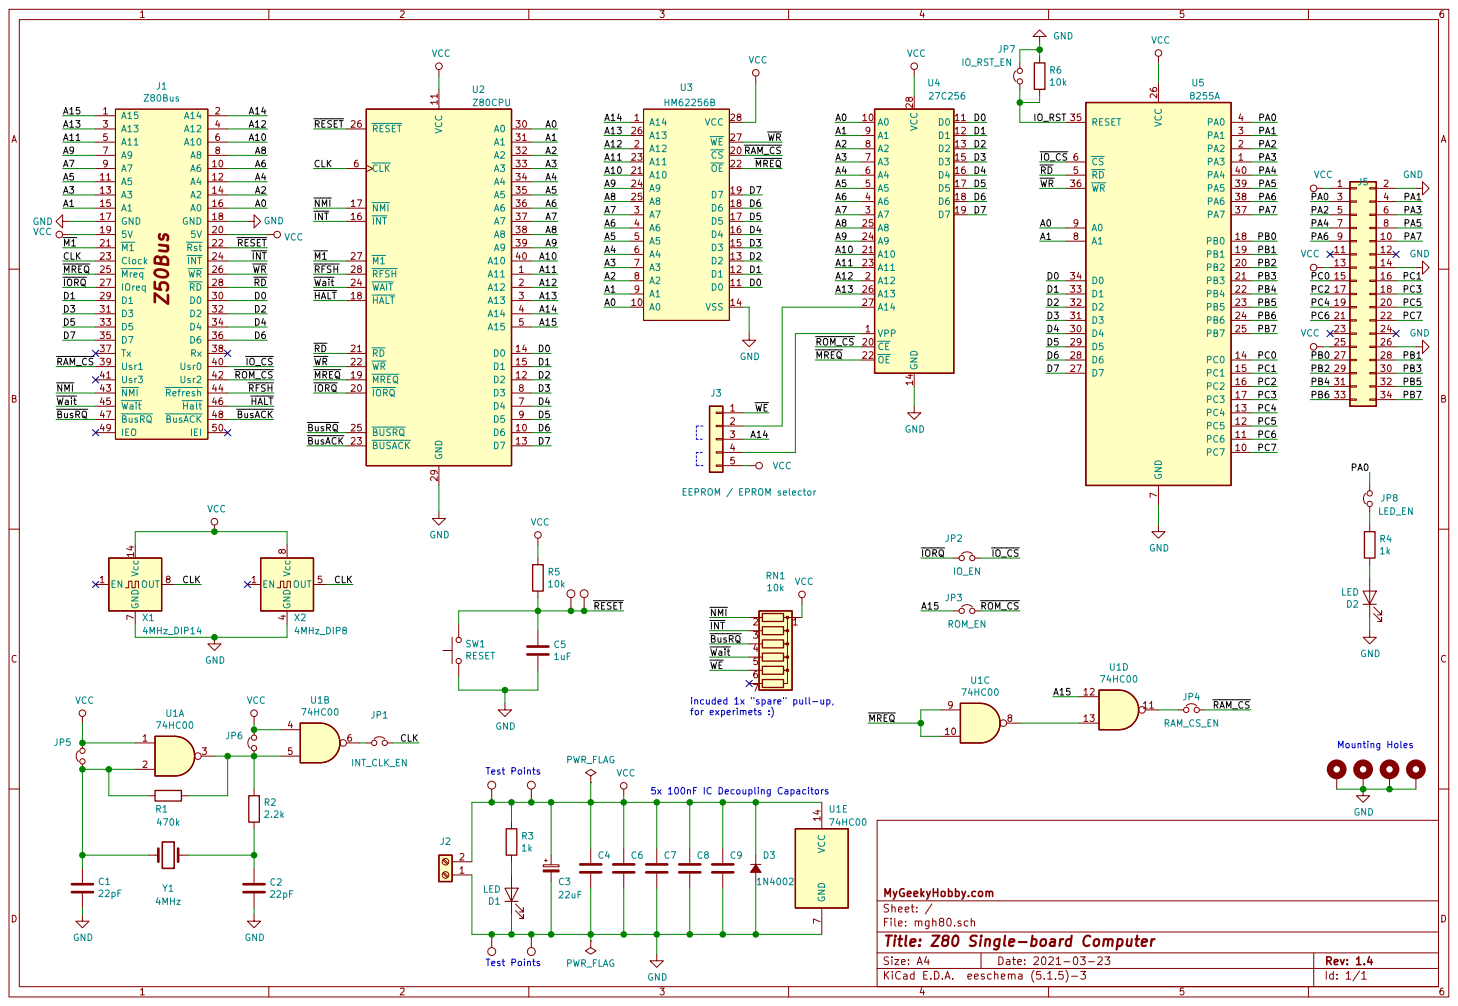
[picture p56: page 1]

J3 EEPROM / EPROM selector VCC

incuded 1x "spare" pull-up,
for experimets :)

File: mgh80.sch Sheet: / MyGeekyHobby.com Y1

Id: 1/1 Title: Z80 Single-board Computer

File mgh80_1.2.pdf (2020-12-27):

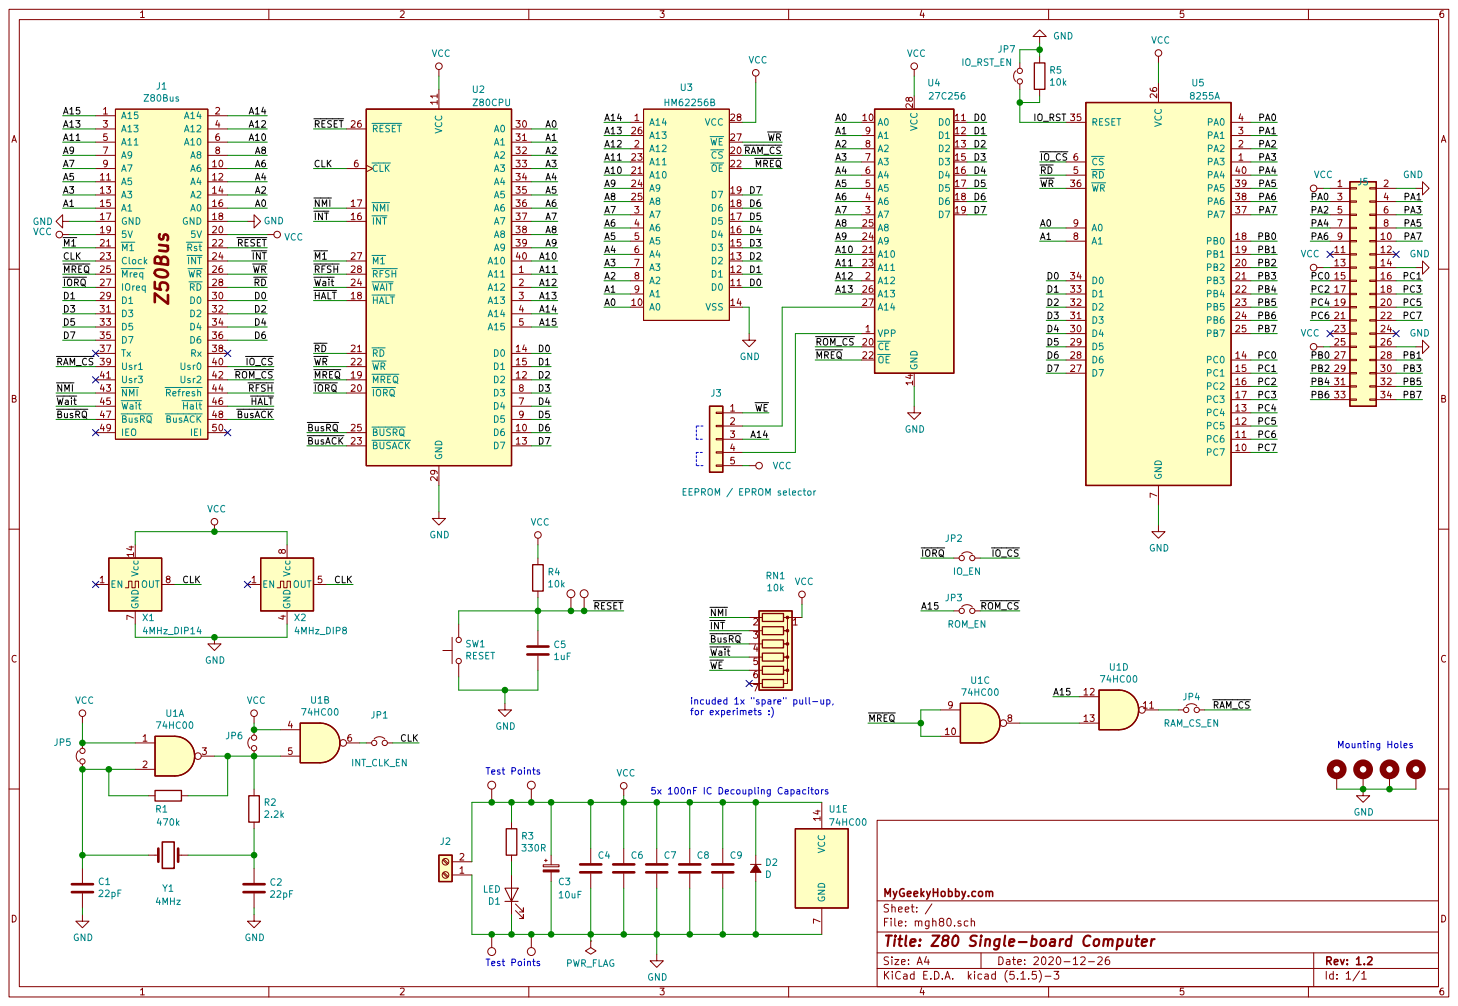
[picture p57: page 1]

J3 EEPROM / EPROM selector VCC

incuded 1x "spare" pull-up,
for experimets :)

5x 100nF IC Decoupling Capacitors Test Points Test Points

File: mgh80.sch Sheet: / MyGeekyHobby.com

Id: 1/1 Title: Z80 Single-board Computer

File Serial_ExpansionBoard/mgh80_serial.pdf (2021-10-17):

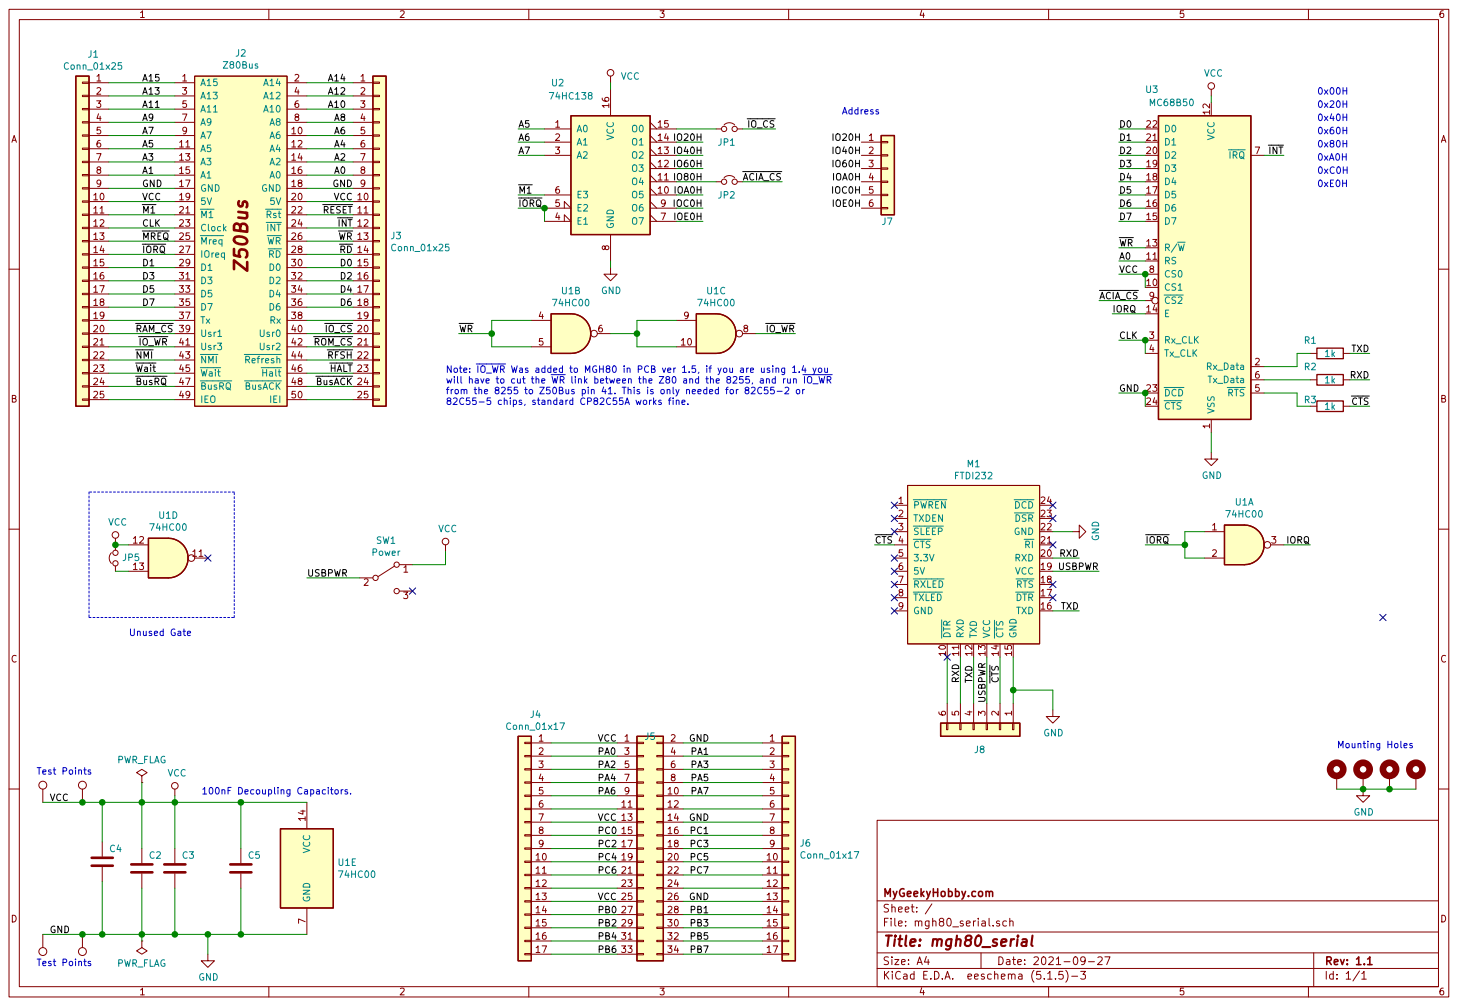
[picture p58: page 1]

10 VCC | IEO 49 A11 5 | 10

11 M1 CLK | | 11
12 | | 12
13 IORQ MREQ | | RD WR 13
14 | | 14
15 | | 15
16 | | 16
17 | | 17
18 | | 18
19 | | 19

21 | 21
22 | RFSH 22
23 | 23
24 | 24
25 | 25

Note: IO_WR Was added to MGH80 in PCB ver 1.5, if you are using 1.4 you will have to cut the WR link between the Z80 and the 8255, and run IO_WR

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

VCC 5 9 | GND GND GND 10 5
2 3 | 4 2
3 5 | 6 3
4 7 | 8 4

7 VCC 13 | 14 7
8 15 | 16 8
9 17 | 18
10 19 | 20 10

12 23 | 24 12
13 VCC 25 | 26 13

File: mgh80_serial.sch Sheet: / MyGeekyHobby.com

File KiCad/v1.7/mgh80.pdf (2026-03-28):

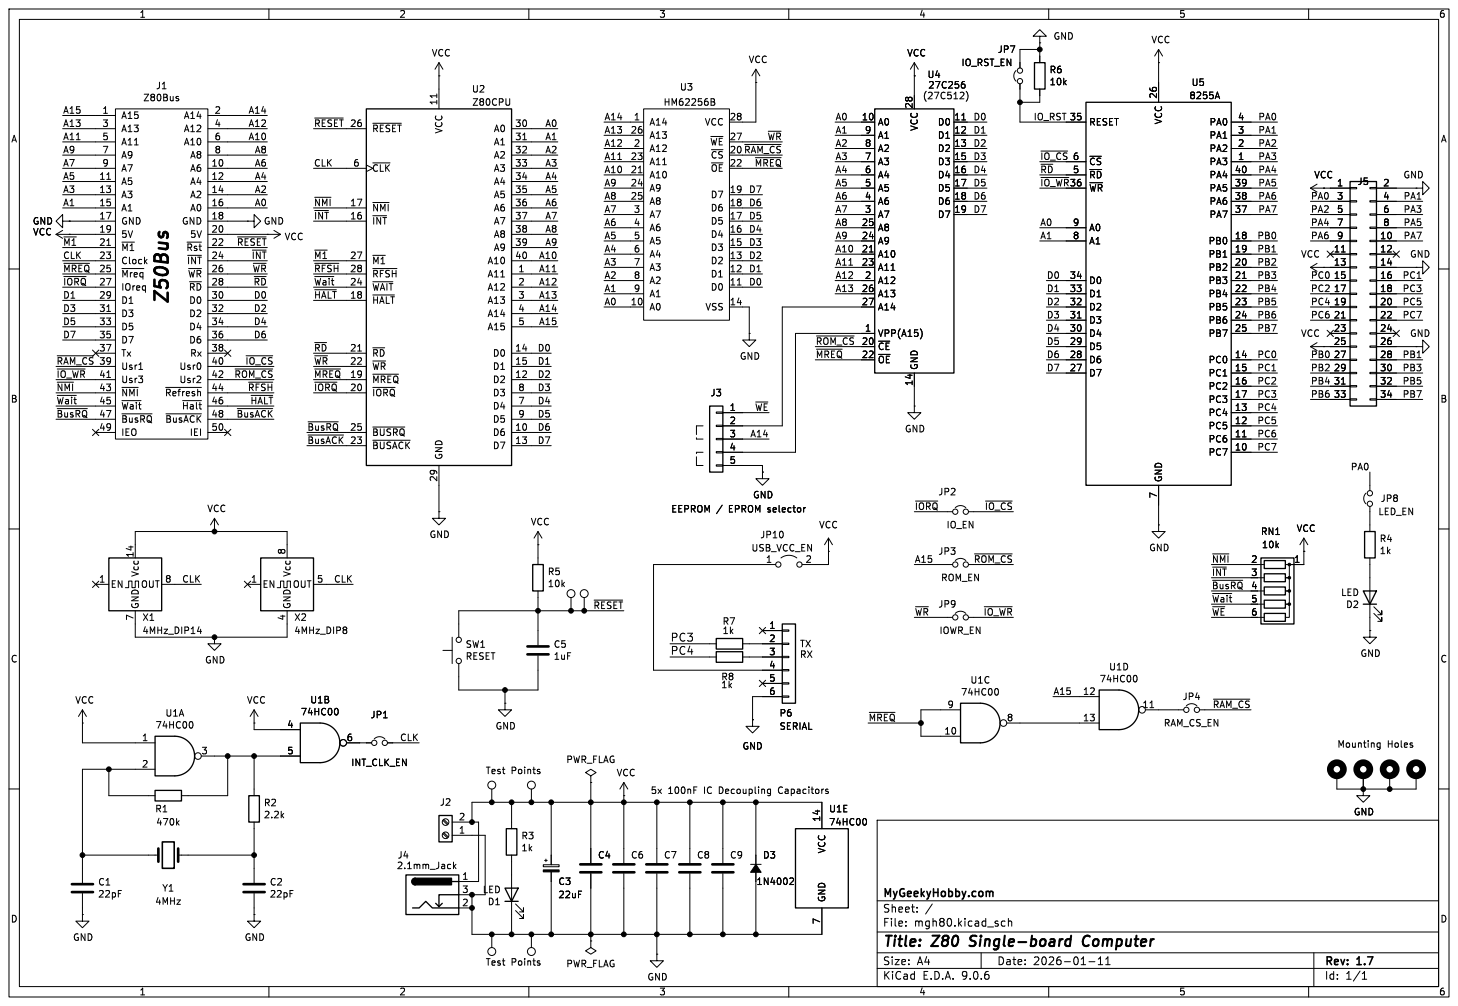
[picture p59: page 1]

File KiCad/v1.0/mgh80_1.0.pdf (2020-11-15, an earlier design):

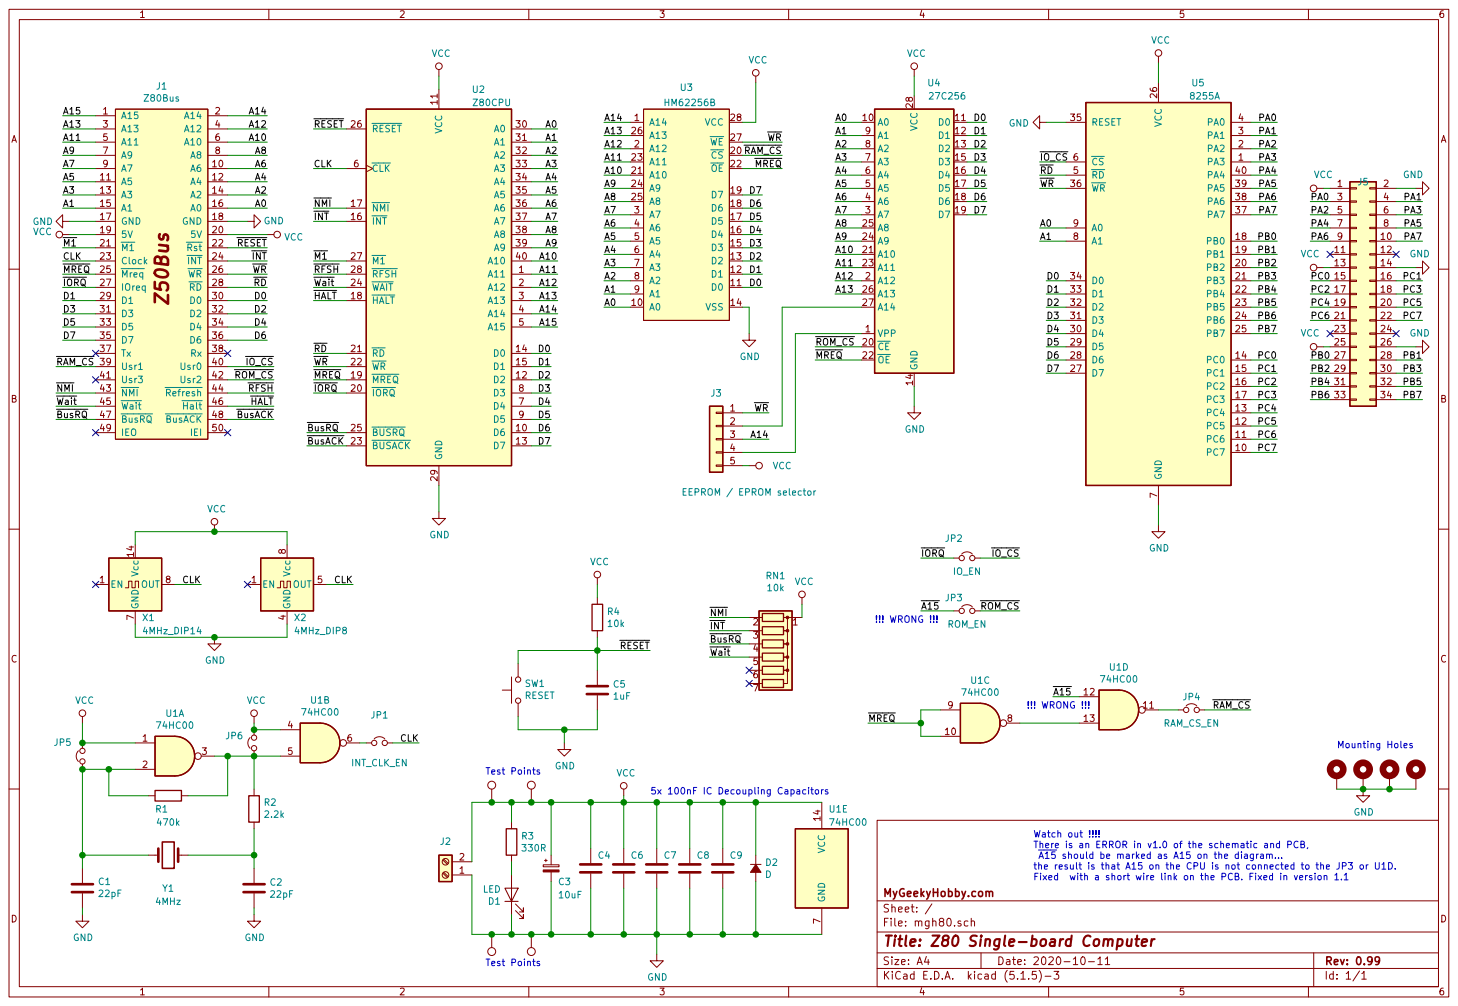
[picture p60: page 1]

A15 should be marked as A15 on the diagram...
the result is that A15 on the CPU is not connected to the JP3 or U1D. Fixed with a short wire link on the PCB. Fixed in version 1.1

File: mgh80.sch Sheet: / MyGeekyHobby.com

Id: 1/1 Title: Z80 Single-board Computer

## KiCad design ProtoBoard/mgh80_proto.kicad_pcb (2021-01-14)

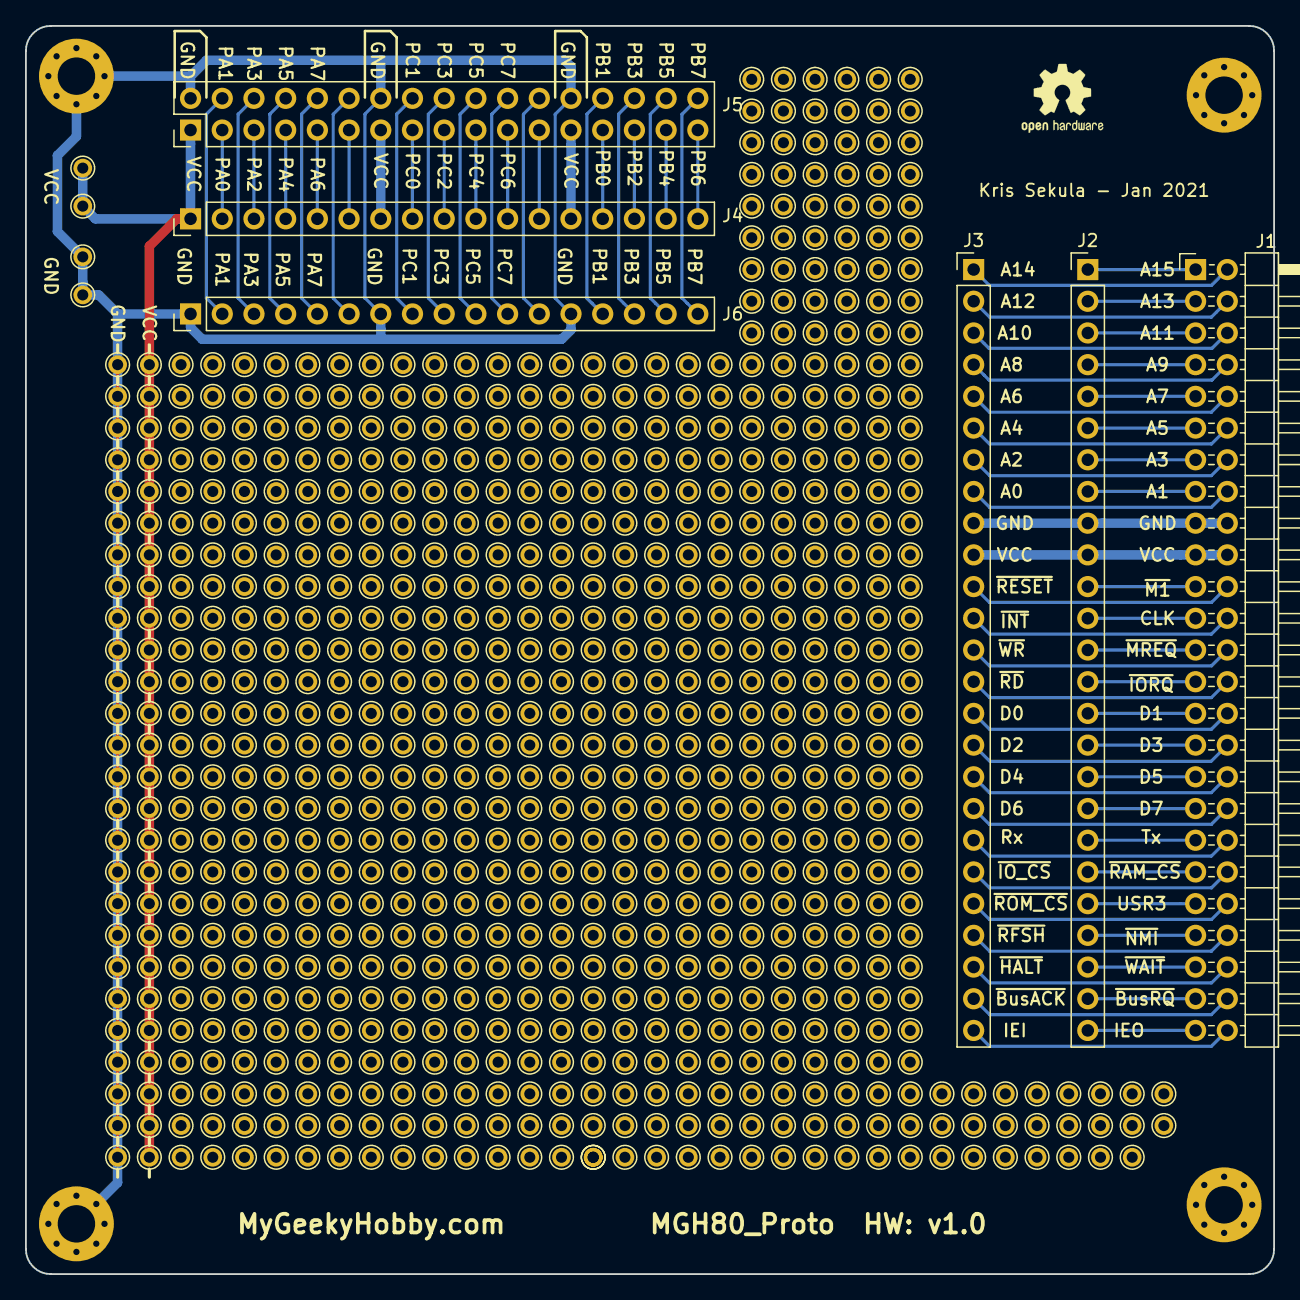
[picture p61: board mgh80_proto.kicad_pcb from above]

Board: 2 copper layers, 100.0 x 100.0 mm, 14 parts (0 on the bottom side), 76 nets.

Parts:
H1, H2, H3, H4: MountingHole_Pad; MountingHole_3mm_Pad_Via
J1: Z80Bus; PinHeader_2x25_P2.54mm_Horizontal
J2, J3: Conn_01x25; PinHeader_1x25_P2.54mm_Vertical
J4, J6: Conn_01x17; PinHeader_1x17_P2.54mm_Vertical
J5: Conn_02x15_Odd_Even; PinHeader_2x17_P2.54mm_Vertical
TP1, TP1#2: 5V VCC; TestPoint_THTPad_D1.5mm_Drill0.7mm
TP2, TP2#2: GND; TestPoint_THTPad_D1.5mm_Drill0.7mm

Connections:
/A0: J1.16, J3.8
/A1: J1.15, J2.8
/A2: J1.14, J3.7
/A3: J1.13, J2.7
/A4: J1.12, J3.6
/A5: J1.11, J2.6
/A6: J1.10, J3.5
/A7: J1.9, J2.5
/A8: J1.8, J3.4
/A9: J1.7, J2.4
/A10: J1.6, J3.3
/A11: J1.5, J2.3
/A12: J1.4, J3.2
/A13: J1.3, J2.2
/A14: J1.2, J3.1
/A15: J1.1, J2.1
/CLK: J1.23, J2.12
/D0: J1.30, J3.15
/D1: J1.29, J2.15
/D2: J1.32, J3.16
/D3: J1.31, J2.16
/D4: J1.34, J3.17
/D5: J1.33, J2.17
/D6: J1.36, J3.18
/D7: J1.35, J2.18
/PA0: J4.2, J5.3
/PA1: J5.4, J6.2
/PA2: J4.3, J5.5
/PA3: J5.6, J6.3
/PA4: J4.4, J5.7
/PA5: J5.8, J6.4
/PA6: J4.5, J5.9
/PA7: J5.10, J6.5
/PB0: J4.14, J5.27
/PB1: J5.28, J6.14
/PB2: J4.15, J5.29
/PB3: J5.30, J6.15
/PB4: J4.16, J5.31
/PB5: J5.32, J6.16
/PB6: J4.17, J5.33
/PB7: J5.34, J6.17
/PC0: J4.8, J5.15
/PC1: J5.16, J6.8
/PC2: J4.9, J5.17
/PC3: J5.18, J6.9
/PC4: J4.10, J5.19
/PC5: J5.20, J6.10
/PC6: J4.11, J5.21
/PC7: J5.22, J6.11
/~BusACK: J1.48, J3.24
/~BusRQ: J1.47, J2.24
/~HALT: J1.46, J3.23
/~INT: J1.24, J3.12
/~IORQ: J1.27, J2.14
/~IO_CS: J1.40, J3.20
/~M1: J1.21, J2.11
/~MREQ: J1.25, J2.13
/~NMI: J1.43, J2.22
/~RAM_CS: J1.39, J2.20
/~RD: J1.28, J3.14
/~RESET: J1.22, J3.11
/~RFSH: J1.44, J3.22
/~ROM_CS: J1.42, J3.21
/~WR: J1.26, J3.13
/~Wait: J1.45, J2.23
GND: H1.1, H2.1, H3.1, H4.1, J1.17, J1.18, J2.9, J3.9, J5.2, J5.14, J5.26, J6.1, J6.7, J6.13, TP2.1, TP2#2.1
unnamed: J1.37, J2.19
unnamed: J1.38, J3.19
unnamed: J1.41, J2.21
unnamed: J1.49, J2.25
unnamed: J1.50, J3.25
unnamed: J4.6, J5.11
unnamed: J4.12, J5.23
unnamed: J5.12, J6.6
unnamed: J5.24, J6.12
VCC: J1.19, J1.20, J2.10, J3.10, J4.1, J4.7, J4.13, J5.1, J5.13, J5.25, TP1.1, TP1#2.1

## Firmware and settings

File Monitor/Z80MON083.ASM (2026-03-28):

;;;;;;;;;;;;;;;;;;;;;;;;;;;;;;;;;;;;;;;;;;;;;;;;;;;;;;;;;;;;;;;
; $Id: Z80MON083.ASM $   10/11/2025     V8.3 
; Z80 Monitor 9600 baud version With Assembler & Disassembler
; V8.0 - Added support for hardwired LED (PORTC-0) & Speaker(PORTC-1)
; V8.1 - Changed FLASHLED
; V8.2 - Improved SENDBYTE & GETBYTE 
; V8.3 - corrected SENDBYTE 
; V8.3mgh - adjusted for MGH80 hardware
; Command Line to Compile: 
; zmac.exe -c -n --oo hex,cim,lst Z80MON08.ASM
;;;;;;;;;;;;;;;;;;;;;;;;;;;;;;;;;;;;;;;;;;;;;;;;;;;;;;;;;;;;;;;

;********************* HARDWARE IO ADR ************************************
; PIO 82C55 I/O
PIO1A:       .EQU    0              ; (INPUT)  IN 1-8
PIO1B:       .EQU    1              ; (INPUT) 
PIO1C:       .EQU    2              ; (OUTPUT)  
PIO1CONT:    .EQU    3              ; CONTROL BYTE PIO 82C55

BDOS:	       .EQU	   0005H	        ;BDOS ENTRY POINT for EMULATOR ONLY
;********************* CONSTANTS ****************************************
RAMTOP:      .EQU    $FFFF          ; 32Kb RAM   8000H-FFFFH
TEMPSTACK    .EQU    $90A8          ; Top of BASIC line input buffer so is "free ram" when BASIC resets
END:         .EQU    $FF            ; Mark END OF TEXT

CT_BLINK:    .EQU    $8080          ; Blink Delay
TX_BYTE:     .EQU    $8081          ; Byte to send
RX_BYTE:     .EQU    $8082          ; Byte recieved
FLAGS_A:     .EQU    $8083          ; Flags A: Bit 0=ECHO                            
COUNT_A:     .EQU    $8085          ; Counter A
COUNT_B:     .EQU    $8086          ; Counter B
COUNT_C:     .EQU    $8087          ; Counter C
ADDR_LO:     .EQU    $8088
ADDR_HI:     .EQU    $8089
TEMP_01:     .EQU    $8091          ; Temp Storage 1
TEMP_02:     .EQU    $8092          ; Temp Storage 2
TEMP_03:     .EQU    $8093          ; Temp Storage 3
TEMP_04:     .EQU    $8094          ; Temp Storage 4
REC_LEN:     .EQU    $8095          ; iHex Record Length 
REC_TYPE:    .EQU    $8096          ; iHex Record Type
REC_CSUM:    .EQU    $8097          ; iHex Record Checksum
ASM_ADDR:    .EQU    $8098          ; Assembler Destination address

ASM_BUF:     .EQU    $80A0          ; 16 byte ASM Input Buffer
OUT_BUF:     .EQU    $80AB          ; 4 byte test buffer(last part of ASM_BUF)  
INS_BUF:     .EQU    $80B0          ; 4 Byte Instruction Buffer
PARM_BUF:    .EQU    $80B4          ; 7 Byte Parm Buffer
VAL_BUF:     .EQU    $80BB          ; 5 Byte Value Buffer
VAL_BUF_HI:  .EQU    $80BB          ; 2 Hi Bytes in Value Buffer
VAL_BUF_LO:  .EQU    $80BD          ; 2 Lo Bytes in Value Buffer
SRC_ADDR:    .EQU    $80C0          ; 2 byte source pointer storage
DES_ADDR:    .EQU    $80C2          ; 2 byte destination pointer storage
BLK_ADDR:    .EQU    $80C4          ; 2 byte table block pointer storage
ROW_ADDR:    .EQU    $80C6          ; 2 byte table row pointer storage
BLK_NUM:     .EQU    $80C8          ; 1 byte Block Number
BLK_SIZE:    .EQU    $80C9          ; 1 byte Block Size
ROW_NUM      .EQU    $80CA          ; 1 byte Row Number  
ML_BUF:      .EQU    $80CB          ; 3 byte ML buffer
ML_BTCOUNT:  .EQU    $80CD          ; Last byte of ML buffer(byte count)
VAL_LO:      .EQU    $80CE          ; Converted value LO
VAL_HI:      .EQU    $80CF          ; Converted value Hi

;*******************************************************************
;*        START AFTER RESET,                                       *
;*        Function....: ready system and restart                   *
;*******************************************************************
             .ORG    $0000
             NOP                   ;A Few NOPs to let things settle down
             NOP
             NOP
             DI                    ; Disable interrupt
             LD     SP,RAMTOP      ; Set stack pointer to top off ram
             JP     MAIN_START     ; jump to Start of program
             
             .BYTE  $FF,$FF,$FF    ; 3 unprogramed bytes

             .byte " MGH80 "  ; text string in rom
             .byte " V 8.3mgh "
             .byte " 01/2026 "

            .ORG    $0030
;*******************************************************************
; External call entry points
; the offsets on these functions should never change
; ther rely on specific ram values for input & output 
;*******************************************************************
XSEND_CHR:  LD    A,(TX_BYTE)
            CALL  SENDBYTE
            RET
            
XGET_CHR:   CALL  GETBYTE
            RET          

XSEND_STR:  LD   HL,(ADDR_LO)
            CALL SENDSTR 
            RET
            
XSEND_HEX:  LD    A,(TX_BYTE)
            CALL  SENDHEX
            RET          
XGET_HEX:   CALL  GETHEXBYTE
            LD    (RX_BYTE),A         
            RET
              
XOUT_P:     LD     B,00h
            LD     A,(TEMP_03)    ; Get Saved Port#
            LD     C,A            ; Move to C
            LD     A,(TEMP_02)    ; Get Value
            OUT    (C),A          ; Output it
            RET
            
XIN_P:      LD     A,(TEMP_03)    ; Get Saved Port#
            LD     C,A
            LD     B,0             
            IN     A,(C)         ; Read Port
            LD     (TEMP_02),A   ; Save it
            RET
  
XDELAY4:    JP     DELAY4
XBEEP       JP     BEEP
XPAUSE      JP     PAUSE            
;*******************************************************************
;*        MAIN PROGRAM                                             *
;*******************************************************************
MAIN_START:  CALL   INIT_PIO    ; programm the PIO
             
             LD     A, 5          ; 5= 1Khz
             LD     B, 1          ; 1= 100ms
             CALL   BEEP             
             
             LD     A,10        
             LD     BC,1000
             CALL   FLASHLED    ; blink LED 10x 20ms / blink
             
             LD     A, 0B2h
             LD     (CT_BLINK),A   ;set default blink delay B2=1/2sec
             
             LD     A,01h
             LD     (FLAGS_A),A  ;Set ECHO ON
             
             LD     HL,TXT_BOOTMS ; get boot message address 
             CALL   SENDSTR       ; send it
           
GET_COMMAND: LD     HL,TXT_PROMPT ; send CR & LF & '>'
             CALL   SENDSTR     

BLINK_START: LD     A, (CT_BLINK)  ;0xB2 = 501.25ms
             LD     B,A
BLINK_LOOP:  IN     A,(PIO1C)      ;READ PORTC       
             BIT    4,A            ;Test BIT 4
             JP     Z,READ_LOOP   ;If LOW get byte
             DEC    C
             JP     NZ,BLINK_LOOP
             DEC    B
             JP     NZ,BLINK_LOOP
             BIT    0,A            ;Test BIT 0
             JP     NZ, LED_OFF    ;If HIGH GOTO LED_OFF
LED_ON:      ORA    1
             OUT    (PIO1C),A 
             JP     BLINK_START    
LED_OFF:     AND    0FEh
             OUT    (PIO1C),A
             JP     BLINK_START
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

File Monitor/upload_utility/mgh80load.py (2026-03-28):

try:
	import serial
	from serial.tools.list_ports import comports
except ImportError as error:
	
	print(f"""Looks like you are missing the serial communication library
You should run the following command to install it:

	   python -m pip install pyserial
	   

... below is some additional debugging information:

{error}

Python: {platform.python_version()}
System: {platform.system()}
""")
	
	input("Press Enter to continue...")
	exit()


import time
import sys

COM_READ_MAX = 5000
COM_FLUSH_MAX = 0.005  # 5 ms
BAUD_RATE = 9600

def wait_for_com_byte(ser, timeout):
    start_time = time.time()
    while (time.time() - start_time) < (timeout / 1000):
        if ser.in_waiting > 0:
            return ser.read(1)  # Read one byte
    return None

def wait_for_com_response(ser, timeout):
    start_time = time.time()
    response = b''
    while (time.time() - start_time) < (timeout / 1000):
        if ser.in_waiting > 0:
            response += ser.read(ser.in_waiting)  # Read all available bytes
            if b'$$$' in response or b'*' in response or b'?' in response or b'E' in response:
                return response
    return None

def open_com(port, baud):
    try:
        ser = serial.Serial(port, baudrate=baud, timeout=0)
        ser.dtr = False  # Disable DTR
        time.sleep(COM_FLUSH_MAX)  # Allow time for port to stabilize
        return ser
    except serial.SerialException as e:
        print(f"ERROR: Failed to open serial port {port}: {e}")
        return None

def ascii_to_hex_val(b):
    if '0' <= b <= '9':
        return ord(b) - ord('0')
    elif 'A' <= b <= 'F':
        return ord(b) - ord('A') + 10
    return 0

def hex_str_to_byte(buf):
    return (ascii_to_hex_val(buf[0]) << 4) + ascii_to_hex_val(buf[1])

def main():
    if len(sys.argv) < 2:
        print("\nERROR! Too Few Arguments\nUsage: python mgh80load.py {filename} {port_#} {execute_after_loading Y/N}\n")
        return 1

    port_num = int(sys.argv[2]) if len(sys.argv) > 2 else 10
    port_name = f'COM{port_num}' if port_num < 10 else f'\\\\.\\COM{port_num}'
    src_file_name = sys.argv[1]

    try:
        with open(src_file_name, 'r') as fp:
            print(f"FILE: '{src_file_name}'")
            
            ser = open_com(port_name, BAUD_RATE)
            if ser is None:
                return 2

            print(f"Com port {port_name} open at {BAUD_RATE} baud.")
            ser.write(b'@')  # Send the attention byte
            time.sleep(0.25)

            response = wait_for_com_response(ser, COM_READ_MAX)
            if response is None or b'$$$' not in response:
                print("\nERROR! No Response from target, hit reset on your MGH80 board")
                ser.close()
                return 3

            print("\nTarget Ready")

            while True:
                line = fp.readline()
                if not line:
                    break
                
                rec_len = hex_str_to_byte(line[1:3])
                rec_type = int(line[7:9])

                if (rec_len == 0) and (rec_type != 0):
                    break
                
                ser.write(b':')  # Send the iHex record start byte
                time.sleep(COM_FLUSH_MAX)
                data_to_send = line.strip().encode()
                ser.write(data_to_send[1:])  # Send data
                print(f"Len: {rec_len} Type: {rec_type} {line.strip()}")  # Print it.

                # Wait for response '*' or '?'
                response = wait_for_com_response(ser, COM_READ_MAX)
                if response is None:
                    print("\nERROR! No Response from target")
                    ser.close()
                    return 4
                
                # Check for the specific response
                if b'*' in response:
                    print("Response: OK")
                elif b'?' in response or b'E' in response:
                    print("Response: ERROR")

                time.sleep(COM_FLUSH_MAX)

            if len(sys.argv) > 3:
                if sys.argv[3] == 'Y':
                    print("\nWill start your program from 0x8100\n")
                    ser.write(b'g')  # Start the program
                elif sys.argv[3] == 'N':
                    ser.write(b'!')  # Reset command

            ser.close()  # Close the serial port
            print("\nDone...")
            return 0

    except FileNotFoundError:
        print(f"ERROR: Cannot Open File '{src_file_name}'")
        return -1
    except Exception as e:
        print(f"ERROR: {e}")
        return -1

if __name__ == "__main__":
    main()

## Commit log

2020-10-12 Added schematic diagram.
2020-11-15 Added sources for v1.0
    [mgh80_1.0.kicad_pcb, mgh80_1.0.sch]
2020-12-27 Added HW v1.2 sources
    [mgh80-B_Cu.gbl, mgh80-B_Mask.gbs, mgh80-B_SilkS.gbo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]
2020-12-27 Added v1.2 schematic in PDF
2021-01-02 Added KiCad sources for v1.3
    [mgh80.kicad_pcb, mgh80.sch]
2021-01-03 added Gerbers for v1.3
2021-01-03 Added v1.3 PCB render
2021-01-14 Create Gerbers
2021-03-09 Added assembly instructions for the DIY kit
2021-04-17 HW ver 1.4 source files added
    [mgh80.kicad_pcb, mgh80.sch]
2021-04-17 Schematic hw 1.4 added
2021-10-17 Schematic v1.5 added
2021-10-17 Added assembly instructions for Hw 1.5
2022-08-29 Serial board instructions added
2024-07-17 PCB mod instructions for mgh80 compatibility
2026-03-28 Added design files for v1.7 and updated instructions
    [mgh80.kicad_pcb, mgh80.kicad_sch, mgh80.sch]

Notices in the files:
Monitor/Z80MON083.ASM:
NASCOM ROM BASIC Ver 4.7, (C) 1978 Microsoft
